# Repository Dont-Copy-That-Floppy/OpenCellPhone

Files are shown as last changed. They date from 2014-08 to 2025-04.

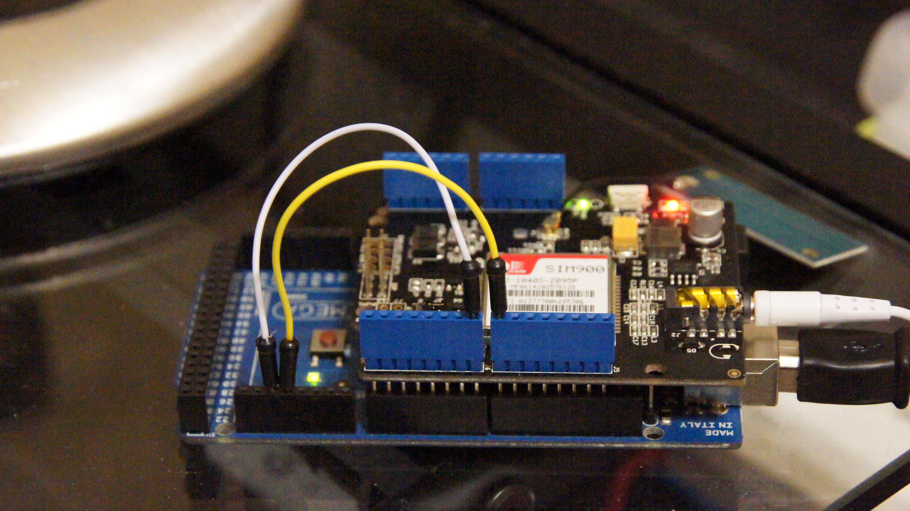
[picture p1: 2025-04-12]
Images/Hardware_Serial.JPG

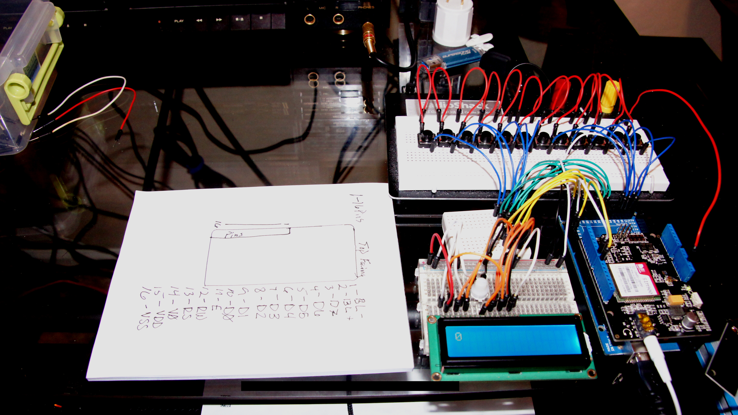
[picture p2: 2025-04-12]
Images/Pre-PrototypePhone_Breadboard.JPG

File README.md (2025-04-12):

# OpenCellPhone

**An open hardware + software cell phone using the global GSM network.**

Arduino-based and fully open-source, OpenCellPhone is a DIY mobile phone project that runs on AT commands, handles SMS/calls, and supports a touch-based interface with a custom-built GUI.

[2014/15 Hackaday Quarterfinalist](https://hackaday.io/project/2478-open-source-cell-phone)

---

## 🚀 Features

- Full support for **SMS send/receive**
- **Touch-based dial pad** and passcode lock screen
- **Call handling** (dial, receive, hang up)
- Basic **notifications**, **call timer**, and **incoming caller display**
- Real-time **clock display** from GSM module (`AT+CCLK`)
- Visual **signal strength** display (`AT+CSQ`)
- **Low-power display handling** with timeout/dim/sleep modes

---

## 🧠 Planned and Future Features

### Needed Features

- Lookup table for pixel width for screen formatting
- Sent SMS display and storage
- Secondary storage for messages
- Emergency calling from passcode screen
- In-call volume adjustment
- Call waiting support (`AT+CHLD`)
- Missed call tracking
- SMS management (delete, reorder, store)
- Signal strength meter
- Re-dial last number (`ATDL`)
- Notification screen with better intelligence

### Future Features

- Bluetooth & FM Radio
- Contact List / Phone Book
- Adjustable screen brightness
- Airplane mode (`AT+CFUN`)
- SMS sorting by sender/contact
- Swipe gestures for UI
- MMS view/send, image handling
- Light sensor and auto-brightness
- MP3/audio playback
- GPS & accelerometer
- Display output
- Web browser
- Ringtones
- Configurable settings via touch UI

---

## 📋 SIM Limitations

- SIM card storage is limited to **30 SMS messages**

---

## ⚙️ Build Info

### Architecture

- Built with **Arduino IDE**
- Written in C/C++ with **low-level serial AT command** integration
- GUI rendered using **RA8875 touchscreen driver**
- Touchscreen and backlight managed through **PWM and pin control**

### Libraries & Tools

- `RA8875` display/touch driver
- Standard `Serial`, `Wire`, and `SPI` Arduino libs
- Custom utility functions for character buffering and cursor logic

---

## 🧪 AT Command References

| Command | Description |
|---|---|
| `ATD*99#` | Dial Access Point |
| `AT+CGDCONT=1,"IP","access.point.name"` | Defines PDP context |
| `AT+VRX` | Record in-call audio |
| `AT+COPS=?` | List available networks |
| `AT+CSQ` | Check signal strength |
| `ATDL` | Redial last number |
| `AT+CHLD` | Call waiting options |

---

## 🧰 Development Setup

### Folder Structure

```text
/PrototypePhone
│
├── /lib                # Optional custom libraries
├── PrototypePhone.ino  # main file

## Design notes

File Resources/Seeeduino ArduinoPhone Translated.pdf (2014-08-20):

### 1. Introduction

ArduinoPhone is a simple wireless telephone device, you can simply realize the phone, answer the phone, send and receive information and Time display function. Communication section uses GPRS Shield to achieve, the display section using TFT Touch Shield, wrote a more complex the firmware, to achieve the UI management, and program screen click function.
The difficulty is:
1. UI management
2. Alphabetic keyboard input
3. Effect zoned screen
4. Serial data processing

### 2. Hardware 2.1 Use Module

- Arduino / Seeeduino
- GPRS Shield
- TFT Touch Shield
- Grove - RTC
- Homemade 7.4V lithium battery charging plate, circuit diagrams attached, you can also use 9V battery

### 2.2 Hardware Connection

GPRS Shield serial communication using hard, TFT Touch Shield 1.0 version (non-SPI interface), a simple repair changed code compatible with version 2.0 TFT Touch Shield Grove -. RTC using I2C interface.
Connection as shown in Figure 2-1.

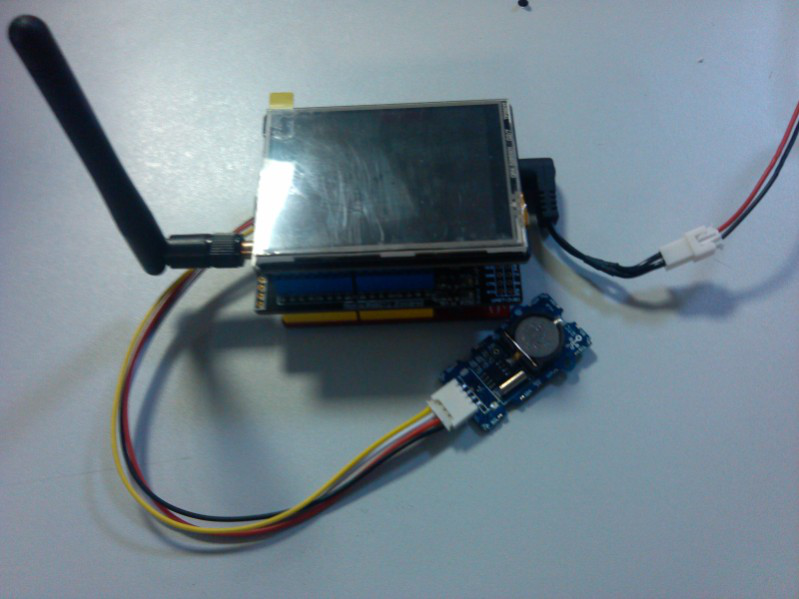
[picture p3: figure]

Figure 2-1 hardware connection diagram

### 3 Software 3.1 Software Process

Main frame is a state machine to switch between the respective states, the following seven states:
- ST_TIME: time mode, real-time displays the current time in this mode, by pressing on the two TFT
- Key to switch to ST_CALL and ST_SMS, if you receive a message, then switched to ST_GETMSG, such as
- If a call comes in, switch to ST_GETCALL.
- ST_CALL: phone mode, then enter the number and dial. Press the call button to switch to ST_CALLING. To Right drag TFT switching to ST_TIME, drag left to switch to ST_SMS
- ST_CALLING: talk mode, if the call ends, the return ST_CALL
- ST_GETCALL: phone into the state, you can use the Accept TFT is turned on or Hand up phone hang
- Off calls. After the call back to the previous state.
- ST_SMS: send a message mode, you can enter the recipient's number and information content, I switched to the Send key
- ST_SENDSMS. Right drag TFT switching to ST_CALL, drag left to switch to ST_GETMSG.
- ST_SENDSMS: Send state, after the information has been sent to return ST_SMS
- ST_GETMSG: read information, press Return TFT can return on a state.

### 3.2 Serial Data Processing

GPRS Shield with Arduino via serial communication, and communication is the process immediately, so opened the Timer 1 every 10ms to detect whether the serial data, if there is data, the stored data to the serial port of a global array serialdata in and the global variable serialGot set. In each of the above said, the state will determine serialGot cycle is valid, If so, the data is read in serialDta and determines the meaning of the data. For example, serial port to receive the "RING" This String, indicating a call comes in, which is switching state, switch to talk mode.

### 3.3 Key letter input

Nokia as we usually like to use, such as pressing a button on the 1st consecutive time, will print a different letter, when build, click when it is a, two under is b, three times is c. To achieve this, you need to determine some time, press After that, if there is the same key within a certain period of time pressed, the buttons as a continuous process. There are many ways to obtain the time interval can be achieved, I tried that millis () function, which returns when the system is running between, the unit is ms. Time intervals tested and found 600ms results were better.

### 3.4 Zoned Screen Effect

You first need to get a lot of data click and slide the screen. Then analyze the data to draw some regularity. When there is a touch behavior when the data through a simple judgment, throw a queue inside, make some judgments, to determine the current behavior is to click on the touch screen or a draw. Here's a little too simple to write, you need to peruse the source code to discover the principle difficulty is debugging parameters.

### 3.5 Instructions for use:

Software process description which has probably explains the use, in fact, this is similar to an ordinary cell phone, does not require much Description and functions are relatively simple.

### 4 Needs To Be Improved

Overall, this firmware to complete a simple function, a lot of areas for improvement:
- Interface design can be more beautiful, because now use TFT Touch Shield 1.0 is no SD card, while Arduino resources within relatively tight, so this part is very difficult to carry out, if you use TFT 2.0, will A lot easier
- Aspects of receiving information, or that problem, with limited resources, so the information can not keep up!
- Address book, you can add this feature, you need to SD cards and other storage devices power down
- Time settings, this due to time constraints, did not do
- Alarm, again, time is running out!
- Other ~

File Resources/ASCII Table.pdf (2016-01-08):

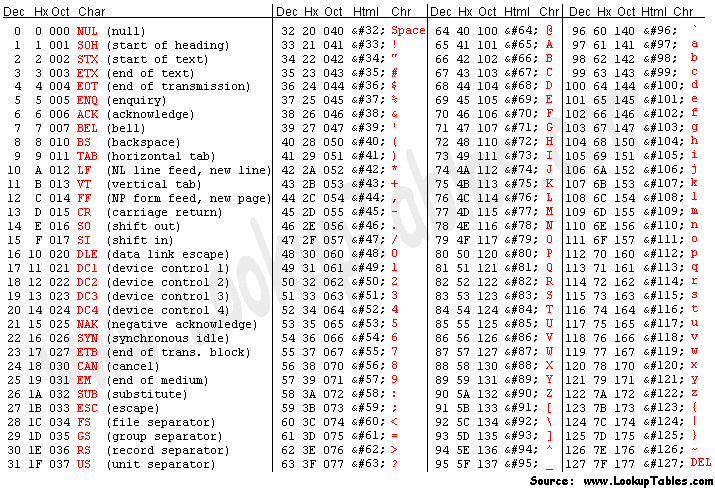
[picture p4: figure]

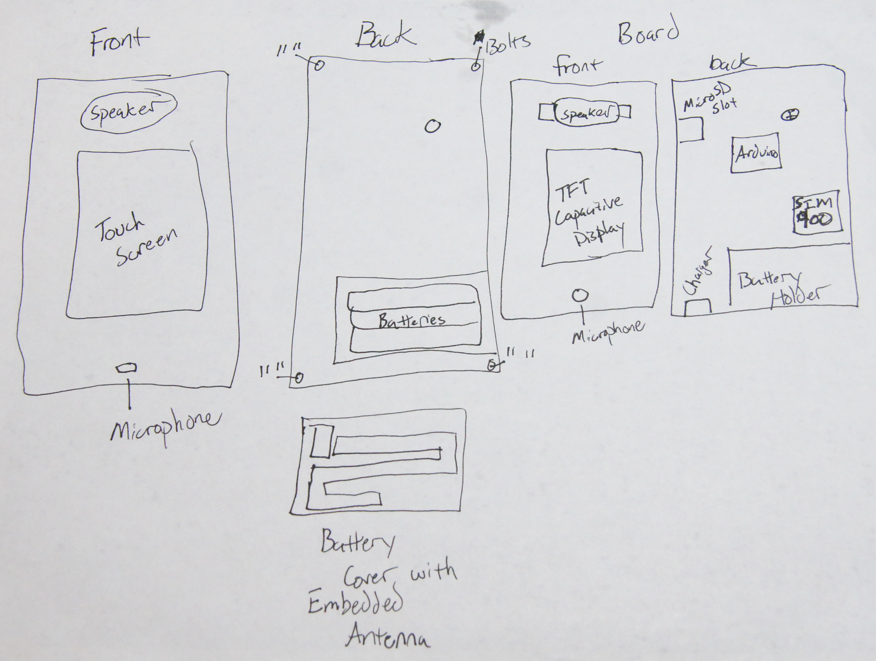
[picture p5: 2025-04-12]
Images/Concept_handdrawing.jpg

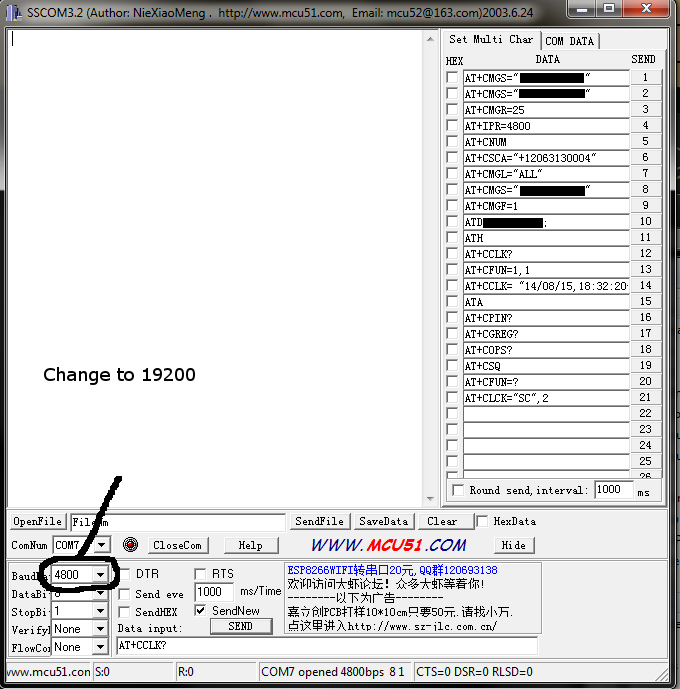
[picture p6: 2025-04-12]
Images/sscom19200.PNG

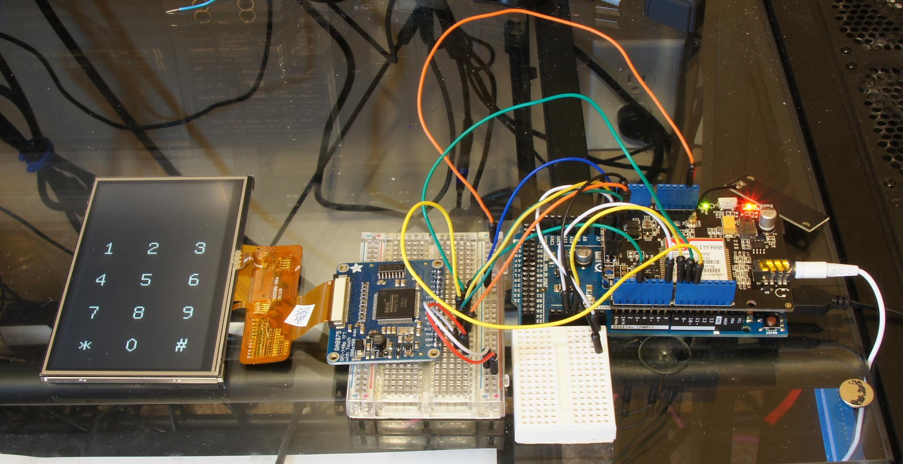
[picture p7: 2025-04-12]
Images/Prototype 8-23.JPG

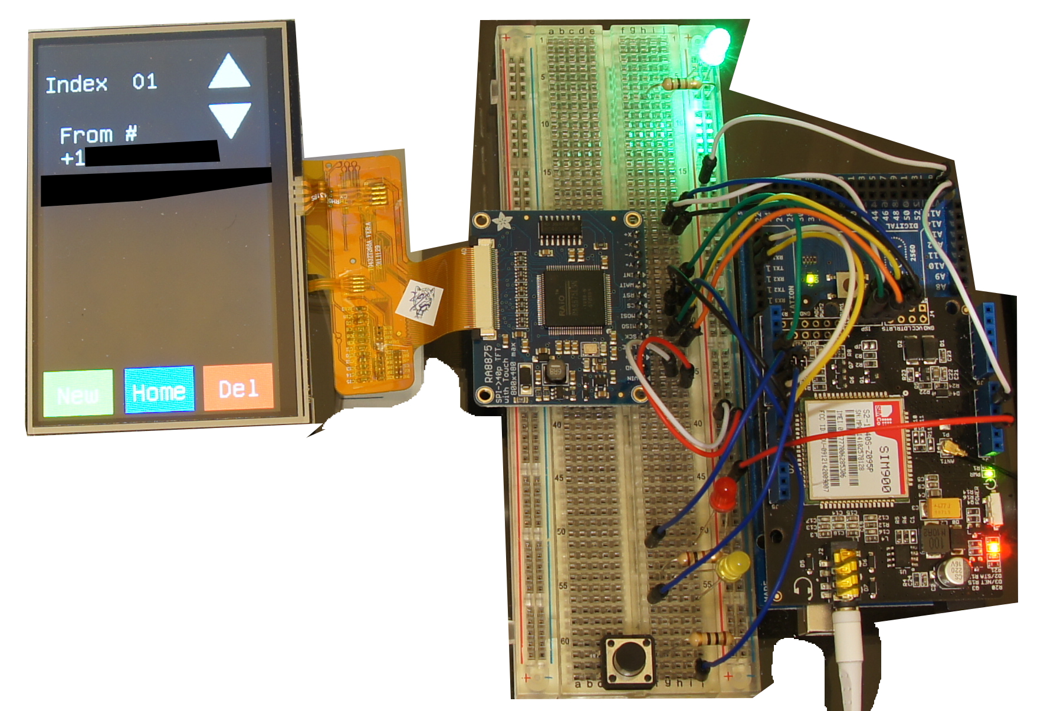
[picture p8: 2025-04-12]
Images/Screen Pictures/SMS_Screen.JPG

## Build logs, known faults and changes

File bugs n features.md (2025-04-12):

---

# 📋 Bugs

- [ ] Delete message needs to go to the **nearest SMS**
- [ ] **Time update** on first start-up takes longer than usual
- [ ] **Not all touches** are registered
- [ ] `clearNotifications` call on line 433 needs more intelligence
- [ ] Prevent user/system from navigating **past available SMS messages**
- [ ] **Reorganize** SMS messages when a lower-numbered one is deleted

---

# 🚧 Needed Features

- [ ] Lookup table for **pixel width** (for screen formatting and text)
- [ ] Function for **user input** to change text position
- [ ] **SMS send** function
- [ ] Ability to **read sent messages**
- [ ] **Store SMS** on secondary storage
- [ ] **Emergency call** from passcode screen
- [ ] Store **missed calls count and number**
- [ ] **Notification screen**
- [ ] **Call time** counter
- [ ] **Call record** screen and data
- [ ] **Clear notifications** functionality
- [ ] **In-call volume** control
- [ ] **Signal strength** display (`AT+CSQ`)
- [ ] **Redial** previous number (`ATDL`)
- [ ] **Call waiting** support (`AT+CHLD=<N>`)
  - `N = 1`: terminate current call, answer call waiting  
  - `N = 2`: set current call to busy, answer waiting call

---

# 🌟 Future Features

- [ ] **Bluetooth**
- [ ] **FM Radio**
- [ ] **Contact list / Phone book**
- [ ] Adjustable **display brightness**
- [ ] **Airplane Mode**
  - Enable: `AT+CFUN=4`
  - Disable: `AT+CFUN=1`
- [ ] Sort SMS by **sender** or **contact**
- [ ] **Swipe screen** left-right for sidebar (e.g., volume control)
- [ ] Show **character limit** during SMS composition
- [ ] **View MMS**
- [ ] **Send MMS**
- [ ] **View images** in MMS
- [ ] **Swipe to clear** notifications
- [ ] **Light sensor** for proximity-based brightness control
- [ ] **Transistor-controlled** ground for speaker (only active in-call)
- [ ] **Transistor-controlled** power for display driver (remove `digitalRead`)
- [ ] Dedicated **Settings screen**
  - Change **screen timeout**
  - Add/Remove **passcode**
  - Adjust **display brightness**
  - Configure **auto brightness thresholds**
  - Set SMS **viewing index manually**
- [ ] **Accelerometer** support (e.g., auto orientation)
- [ ] Use **custom ringtones**
- [ ] **MP3/Audio player**
- [ ] **GPS** sensor
- [ ] **Display-Out** support
- [ ] **Web browser**

---

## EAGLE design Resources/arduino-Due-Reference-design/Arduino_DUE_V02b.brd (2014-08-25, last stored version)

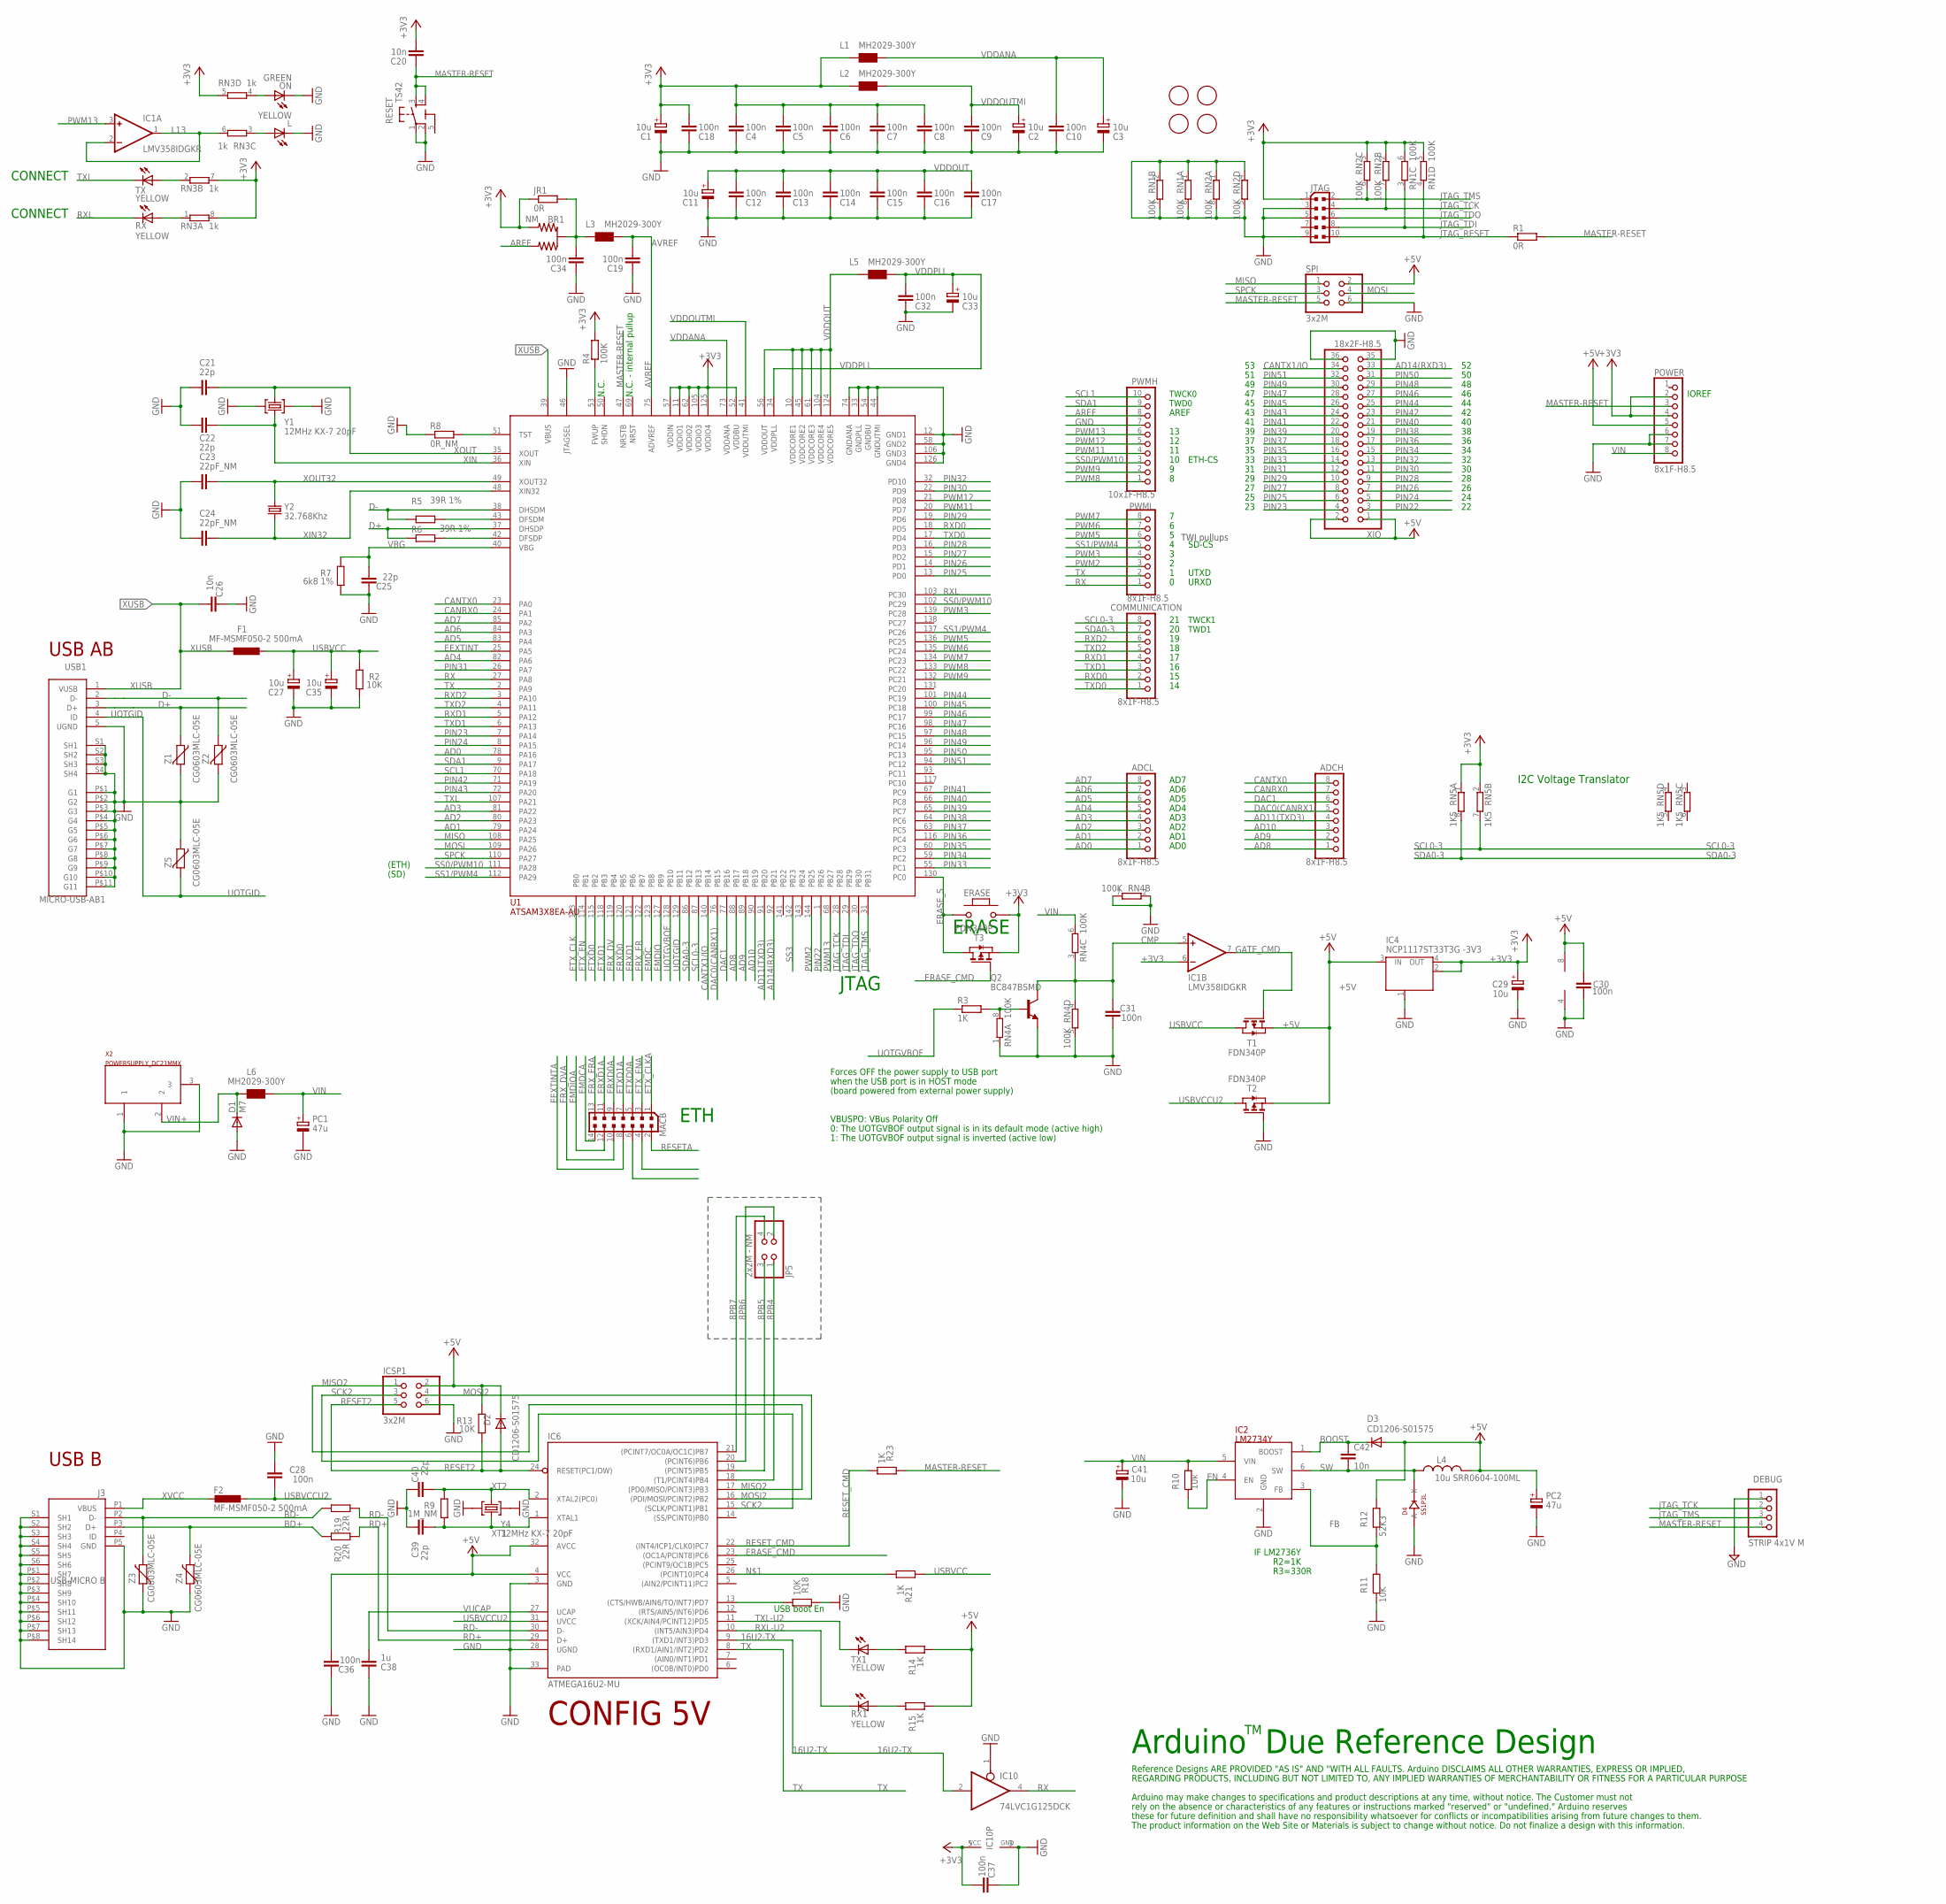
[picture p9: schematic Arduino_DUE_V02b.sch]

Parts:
ADCH: 8x1F-H8.5; 1X08
ADCL: 8x1F-H8.5; 1X08
BR1: NM; J0402
C1, C2, C3, C11, C27, C29, C33, C35, C41: 10u; SMC_B
C4, C5, C6, C7, C8, C9, C10, C12, C13, C14, C15, C16, C17, C18, C19, C28, C30, C31, C32, C34, C36, C37: 100n; C0402
C20, C26: 10n; C0402
C21, C22, C25, C39, C40: 22p; C0402
C23, C24: 22pF_NM; C0402
C38: 1u; C0402
C42: 10n; C0603-ROUND
COMMUNICATION: 8x1F-H8.5; 1X08
D1: M7; SMB
D2, D3: CD1206-S01575; MINIMELF
D4: SS1P3L; DO220AAL
DEBUG: STRIP 4x1V M; 1X04
ERASE: MYSMD_PB157; SMD_157SW
F1, F2: MF-MSMF050-2 500mA; L1812
FID1, FID2, FID3, FID4: FIDUCIALMOUNT; FIDUCIA-MOUNT
IC1: LMV358IDGKR; MSOP08
IC2: LM2734Y; SOT23-6
IC4: NCP1117ST33T3G -3V3; SOT223
IC6: ATMEGA16U2-MU; MLF32
IC10: 74LVC1G125DCK; SC70-5
ICSP1: 3x2M; 2X03
J3: USB-MICRO B; CON2_USB_MICRO_B_AT
JP5: 2x2M - NM; 2X02
JR1: 0R; R0402
JTAG: PINHEAD_PINHD-2X5PASSO127; PINHEAD_2X05_127
L: YELLOW; CHIP-LED0805
L1, L2, L3, L5, L6: MH2029-300Y; 0805
L4: 10u SRR0604-100ML; SRR0604
MACB: PINHEAD_PINHD-2X7PASSO127; PINHEAD_2X07_127
ON: GREEN; CHIP-LED0805
PC1, PC2: 47u; PANASONIC_D
POWER: 8x1F-H8.5; 1X08
PWMH: 10x1F-H8.5; 1X10
PWML: 8x1F-H8.5; 1X08
Q2: BC847BSMD; SOT23
R1: 0R; R0402
R2, R13, R18: 10K; R0402
R3, R14, R15, R21, R23: 1K; R0402
R4: 100K; R0402
R5, R6: 39R 1%; R0402
R7: 6k8 1%; R0603-ROUND
R8: 0R_NM; R0402
R9: 1M_NM; R0402
R10: 10k; R0402
R11: 10K; R0603-ROUND
R12: 52K3; R0603-ROUND
R19, R20: 22R; R0402
RESET: TS42
RN1, RN2, RN4: 100K; CAT16
RN3: 1k; CAY16
RN5: 1K5; CAT16
RX, RX1: YELLOW; CHIP-LED0805
SPI: 3x2M; 2X03
T1, T2, T3: FDN340P; SOT-23
TX, TX1: YELLOW; CHIP-LED0805
U1: ATSAM3X8EA-AU; LQFP144
USB1: MICRO-USB-AB1; MCR-AB1-S-RA-SMT
X2: POWERSUPPLY_DC21MMX; POWERSUPPLY_DC-21MM
XIO: 18x2F-H8.5; 2X18
Y1, Y4: 12MHz KX-7 20pF; CRYSTAL-3.2-2.5
Y2: 32.768Khz; RESONATOR_EPSON_FC_145
Z1, Z2, Z3, Z4, Z5: CG0603MLC-05E; CT/CN0603

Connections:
5-GND: RESET.5 (5-GND)
8PB4: IC6.18 ((T1/PCINT4)PB4), JP5.1
8PB5: IC6.19 ((PCINT5)PB5), JP5.3
8PB6: IC6.20 ((PCINT6)PB6), JP5.2
8PB7: IC6.21 ((PCINT7/OC0A/OC1C)PB7), JP5.4
16U2-TX: IC6.9 ((TXD1/INT3)PD3), IC10.2 (I)
+3V3: BR1.3 (2), C1.+, C4.2, C5.2, C6.2, C7.2, C8.2, C18.2, C20.2, C29.+, C37.1, ERASE.1, IC1.6 (-IN), IC4.2 (OUT), IC4.4 (OUT), IC10.5 (VCC), JR1.1, JTAG.1, L1.1, L2.1, POWER.2, POWER.4, R4.2, RN1.5 (2), RN1.6 (2), RN2.2 (1), RN2.3 (1), RN3.5 (2), RN3.7 (2), RN3.8 (2), RN5.1, RN5.2 (1), T3.2 (S), U1.11 (VDDIO1), U1.52 (VDDBU), U1.57 (VDDIN), U1.62 (VDDIO2), U1.105 (VDDIO3), U1.125 (VDDIO4)
+5V: C30.2, C36.1, D2.C, D3.A, IC1.8 (V+), IC4.3 (IN), IC6.4 (VCC), IC6.32 (AVCC), ICSP1.2, L4.P$2 (2), PC2.+, POWER.5, R12.1, R13.2, R14.1, R15.1, SPI.2, T1.2 (S), T2.2 (S), XIO.1, XIO.2
AD0: ADCL.1, U1.78 (PA16)
AD1: ADCL.2, U1.79 (PA24)
AD2: ADCL.3, U1.80 (PA23)
AD3: ADCL.4, U1.81 (PA22)
AD4: ADCL.5, U1.82 (PA6)
AD5: ADCL.6, U1.83 (PA4)
AD6: ADCL.7, U1.84 (PA3)
AD7: ADCL.8, U1.85 (PA2)
AD8: ADCH.1, U1.88 (PB17)
AD9: ADCH.2, U1.89 (PB18)
AD10: ADCH.3, U1.90 (PB19)
AD11(TXD3): ADCH.4, U1.91 (PB20)
AD14(RXD3): U1.92 (PB21), XIO.33
AREF: BR1.1, PWMH.8
AVREF: C19.2, L3.2, U1.75 (ADVREF)
AVREFL: BR1.2 (C), C34.2, JR1.2, L3.1
BD+: J3.P3 (D+), R20.2, Z4.2
BD-: J3.P2 (D-), R19.2, Z3.2
BOOST: C42.1, D3.C, IC2.1 (BOOST)
CANRX0: ADCH.7, U1.24 (PA1)
CANTX0: ADCH.8, U1.23 (PA0)
CANTX1/IO: U1.140 (PB14), XIO.34
CMP: C31.2, IC1.5 (+IN), Q2.3 (C), RN4.3 (1), RN4.4 (1)
D+: R6.1, U1.37 (DHSDP), USB1.3 (D+), Z1.1
D-: R5.1, U1.38 (DHSDM), USB1.2 (D-), Z2.1
DAC0(CANRX1): ADCH.5, U1.76 (PB15)
DAC1: ADCH.6, U1.77 (PB16)
DTR: IC6.13 ((CTS/HWB/AIN6/TO/INT7)PD7), R18.1
EEXTINT: U1.25 (PA5)
EEXTINTA: MACB.8
EMDC: U1.123 (PB8)
EMDCA: MACB.14
EMDIO: U1.127 (PB9)
EMDIOA: MACB.12 (13)
EN: IC2.4 (EN), R10.2
ERASE_CMD: IC6.23 ((OC1A/PCINT8)PC6), T3.3 (G)
ERASE_S: ERASE.2, T3.1 (D), U1.130 (PC0)
ERXD0: U1.120 (PB5)
ERXD0A: MACB.9
ERXD1: U1.121 (PB6)
ERXD1A: MACB.11
ERX_DV: U1.119 (PB4)
ERX_DVA: MACB.10
ERX_ER: U1.122 (PB7)
ERX_ERA: MACB.13 (12)
ETXD0: U1.115 (PB2)
ETXD0A: MACB.5
ETXD1: U1.118 (PB3)
ETXD1A: MACB.7
ETX_CLK: U1.113 (PB0)
ETX_CLKA: MACB.1
ETX_EN: U1.114 (PB1)
ETX_ENA: MACB.3
FB: IC2.3 (FB), R11.1, R12.2
GATE_CMD: IC1.7 (OUT), T1.3 (G)
GND: C1.-, C2.-, C3.-, C4.1, C5.1, C6.1, C7.1, C8.1, C9.1, C10.1, C11.-, C12.1, C13.1, C14.1, C15.1, C16.1, C17.1, C18.1, C19.1, C21.2, C22.2, C23.2, C24.2, C25.2, C26.2, C27.-, C28.2, C29.-, C30.1, C31.1, C32.1, C33.-, C34.1, C35.-, C36.2, C37.2, C38.2, C39.2, C40.2, C41.-, D1.A, D4.P$2 (A), DEBUG.1, IC1.4 (V-), IC2.2 (GND), IC4.1 (GND/ADJ), IC6.3 (GND), IC6.28 (UGND), IC6.33 (PAD), IC10.1 (OE), IC10.3 (GND), ICSP1.6, J3.P5 (GND), J3.P$1 (SH7), J3.P$2 (SH8), J3.P$3 (SH9), J3.P$4 (SH10), J3.P$5 (SH11), J3.P$6 (SH12), J3.P$7 (SH13), J3.P$8 (SH14), J3.S1 (SH1), J3.S2 (SH2), J3.S3 (SH3), J3.S4 (SH4), J3.S5 (SH5), J3.S6 (SH6), JTAG.3, JTAG.5, JTAG.9, L.C, ON.C, PC1.-, PC2.-, POWER.6, POWER.7, PWMH.7, Q2.2 (E), R2.1, R7.1, R8.1, R11.2, R18.2, RESET.1, RESET.2, RN1.1, RN1.2 (1), RN1.7 (2), RN1.8 (2), RN2.1, RN2.4 (1), RN2.5 (2), RN2.8 (2), RN4.1, RN4.2 (1), RN4.5 (2), RN4.7 (2), SPI.6, T2.3 (G), U1.12 (GND1), U1.33 (GNDPLL), U1.44 (GNDUTMI), U1.46 (JTAGSEL), U1.54 (GNDBU), U1.58 (GND2), U1.74 (GNDANA), U1.106 (GND3), U1.126 (GND4), USB1.5 (UGND), USB1.P$1 (G1), USB1.P$2 (G2), USB1.P$3 (G3), USB1.P$4 (G4), USB1.P$5 (G5), USB1.P$6 (G6), USB1.P$7 (G7), USB1.P$8 (G8), USB1.P$9 (G9), USB1.P$10 (G10), USB1.P$11 (G11), USB1.S1 (SH1), USB1.S2 (SH2)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
JTAG_RESET: JTAG.10, R1.1, RN1.4 (1)
JTAG_TCK: DEBUG.2, JTAG.4, RN2.7 (2), U1.28 (PB28)
JTAG_TDI: JTAG.8, RN1.3 (1), U1.29 (PB29)
JTAG_TDO: JTAG.6, U1.30 (PB30)
JTAG_TMS: DEBUG.3, JTAG.2, RN2.6 (2), U1.31 (PB31)
L13: IC1.1 (OUT), IC1.2 (-IN), RN3.6 (2)
MASTER-RESET: C20.1, DEBUG.4, POWER.3, R1.2, R23.2, RESET.3, RESET.4, SPI.5, U1.47 (NRSTB)
MISO: SPI.1, U1.108 (PA25)
MISO2: IC6.17 ((PD0/MISO/PCINT3)PB3), ICSP1.1
MOSI: SPI.4, U1.109 (PA26)
MOSI2: IC6.16 ((PDI/MOSI/PCINT2)PB2), ICSP1.4
unnamed: IC6.26 ((PCINT10)PC4), R21.1
unnamed: L.A, RN3.3 (1)
unnamed: ON.A, RN3.4 (1)
unnamed: R15.2, RX1.A
unnamed: R8.2, U1.51 (TST)
unnamed: Q2.1 (B), R3.2, RN4.8 (2)
unnamed: R4.1, U1.53 (FWUP)
unnamed: R5.2, U1.43 (DFSDM)
unnamed: R6.2, U1.42 (DFSDP)
unnamed: R14.2, TX1.A
unnamed: RN3.1, RX.A
unnamed: RN3.2 (1), TX.A
PIN22: U1.1 (PB26), XIO.3
PIN23: U1.7 (PA14), XIO.4
PIN24: U1.8 (PA15), XIO.5
PIN25: U1.13 (PD0), XIO.6
PIN26: U1.14 (PD1), XIO.7
PIN27: U1.15 (PD2), XIO.8
PIN28: U1.16 (PD3), XIO.9
PIN29: U1.19 (PD6), XIO.10
PIN30: U1.22 (PD9), XIO.11
PIN31: U1.26 (PA7), XIO.12
PIN32: U1.32 (PD10), XIO.13
PIN33: U1.55 (PC1), XIO.14
PIN34: U1.59 (PC2), XIO.15
PIN35: U1.60 (PC3), XIO.16
PIN36: U1.116 (PC4), XIO.17
PIN37: U1.63 (PC5), XIO.18
PIN38: U1.64 (PC6), XIO.19
PIN39: U1.65 (PC7), XIO.20
PIN40: U1.66 (PC8), XIO.21
PIN41: U1.67 (PC9), XIO.22
PIN42: U1.71 (PA19), XIO.23
PIN43: U1.72 (PA20), XIO.24
PIN44: U1.101 (PC19), XIO.25
PIN45: U1.100 (PC18), XIO.26
PIN46: U1.99 (PC17), XIO.27
PIN47: U1.98 (PC16), XIO.28
PIN48: U1.97 (PC15), XIO.29
PIN49: U1.96 (PC14), XIO.30
PIN50: U1.95 (PC13), XIO.31
PIN51: U1.94 (PC12), XIO.32
PWM2: PWML.3, U1.144 (PB25)
PWM3: PWML.4, U1.139 (PC28)
PWM5: PWML.6, U1.136 (PC25)
PWM6: PWML.7, U1.135 (PC24)
PWM7: PWML.8, U1.134 (PC23)
PWM8: PWMH.1, U1.133 (PC22)
PWM9: PWMH.2, U1.132 (PC21)
PWM11: PWMH.4, U1.20 (PD7)
PWM12: PWMH.5, U1.21 (PD8)
PWM13: IC1.3 (+IN), PWMH.6, U1.68 (PB27)
RD+: IC6.29 (D+), R20.1
RD-: IC6.30 (D-), R19.1
RESET2: D2.A, IC6.24 (RESET(PC1/DW)), ICSP1.5, R13.1
RESETA: MACB.2
RESET_CMD: IC6.22 ((INT4/ICP1/CLK0)PC7), R23.1
RX: IC10.4 (O), PWML.1, U1.27 (PA8)
RXD0: COMMUNICATION.2, U1.18 (PD5)
RXD1: COMMUNICATION.4, U1.5 (PA12)
RXD2: COMMUNICATION.6, U1.3 (PA10)
RXL: RX.C, U1.103 (PC30)
RXL-U2: IC6.10 ((INT5/AIN3)PD4), RX1.C
SCK2: IC6.15 ((SCLK/PCINT1)PB1), ICSP1.3
SCL0-3: COMMUNICATION.8, RN5.7 (2), U1.87 (PB13)
SCL1: PWMH.10, U1.70 (PA18)
SDA0-3: COMMUNICATION.7, RN5.8 (2), U1.86 (PB12)
SDA1: PWMH.9, U1.9 (PA17)
SPCK: SPI.3, U1.110 (PA27)
SS0/PWM10: PWMH.3, U1.102 (PC29), U1.111 (PA28)
SS1/PWM4: PWML.5, U1.112 (PA29), U1.137 (PC26)
SS3: U1.142 (PB23)
SW: C42.2, D4.P$1 (K), IC2.6 (SW), L4.P$1 (1)
TX: IC6.8 ((RXD1/AIN1/INT2)PD2), PWML.2, U1.2 (PA9)
TXD0: COMMUNICATION.1, U1.17 (PD4)
TXD1: COMMUNICATION.3, U1.6 (PA13)
TXD2: COMMUNICATION.5, U1.4 (PA11)
TXL: TX.C, U1.107 (PA21)
TXL-U2: IC6.11 ((XCK/AIN4/PCINT12)PD5), TX1.C
UOTGID: U1.129 (PB11), USB1.4 (ID), Z5.2
UOTGVBOF: R3.1, U1.128 (PB10)
USBVCC: C27.+, C35.+, F1.1, R2.2, R21.2, T1.1 (D)
USBVCCU2: C28.1, F2.1, IC6.31 (UVCC), T2.1 (D)
VBG: C25.1, R7.2, U1.40 (VBG)
VDDANA: C3.+, C10.2, L1.2, U1.73 (VDDANA)
VDDOUT: C11.+, C12.2, C13.2, C14.2, C15.2, C16.2, C17.2, L5.1, U1.10 (VDDCORE1), U1.45 (VDDCORE2), U1.56 (VDDOUT), U1.61 (VDDCORE3), U1.104 (VDDCORE4), U1.124 (VDDCORE5)
VDDOUTMI: C2.+, C9.2, L2.2, U1.41 (VDDUTMI)
VDDPLL: C32.2, C33.+, L5.2, U1.34 (VDDPLL)
VIN: C41.+, IC2.5 (VIN), L6.1, PC1.+, POWER.8, R10.1, RN4.6 (2)
VIN+: D1.C, L6.2, X2.2
VUCAP: C38.1, IC6.27 (UCAP)
XIN: C22.1, U1.36 (XIN), Y1.1 (C1)
XIN32: C24.1, U1.48 (XIN32), Y2.P$2 (2)
XOUT: C21.1, U1.35 (XOUT), Y1.3 (C2)
XOUT32: C23.1, U1.49 (XOUT32), Y2.P$1 (1)
XT1: C39.1, IC6.1 (XTAL1), R9.1, Y4.1 (C1)
XT2: C40.1, IC6.2 (XTAL2(PC0)), R9.2, Y4.3 (C2)
XUSB: C26.1, F1.2, U1.39 (VBUS), USB1.1 (VUSB)
XVCC: F2.2, J3.P1 (VBUS)

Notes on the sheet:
TWI pullups
TWCK1
TWD1
IOREF
TWCK0
TWD0
AD1
AD2
AD3
AD4
AD5
AD6
AD0
USB AB
AREF
AD7
SD-CS
Forces OFF the power supply to USB port
when the USB port is in HOST mode
(board powered from external power supply)
N.C.
JTAG
ERASE
CONNECT
VBUSPO: VBus Polarity Off
0: The UOTGVBOF output signal is in its default mode (active high)
1: The UOTGVBOF output signal is inverted (active low)
ETH
UTXD
URXD
(ETH)
(SD)
ETH-CS
I2C Voltage Translator
USB boot En
IF LM2736Y
R2=1K
R3=330R
CONFIG 5V
USB B

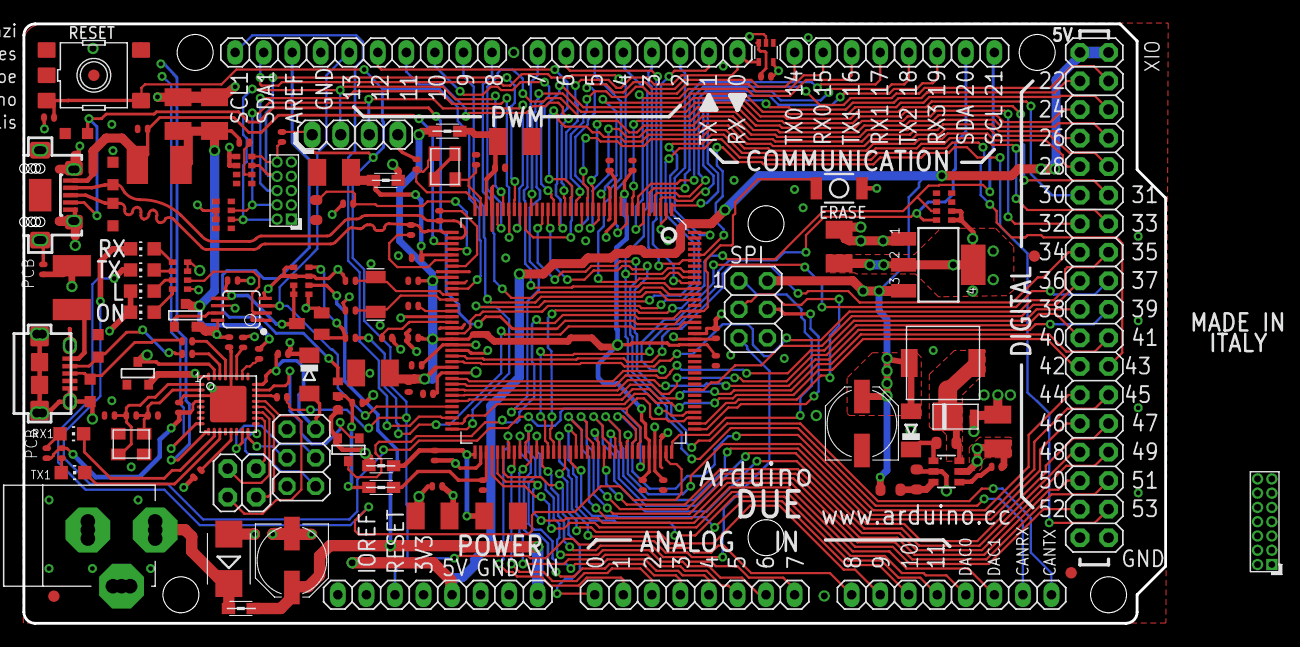
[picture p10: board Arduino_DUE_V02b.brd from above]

Board: 4 copper layers, 101.6 x 53.3 mm, 130 parts (0 on the bottom side), 149 nets.

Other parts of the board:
E$1: DISC

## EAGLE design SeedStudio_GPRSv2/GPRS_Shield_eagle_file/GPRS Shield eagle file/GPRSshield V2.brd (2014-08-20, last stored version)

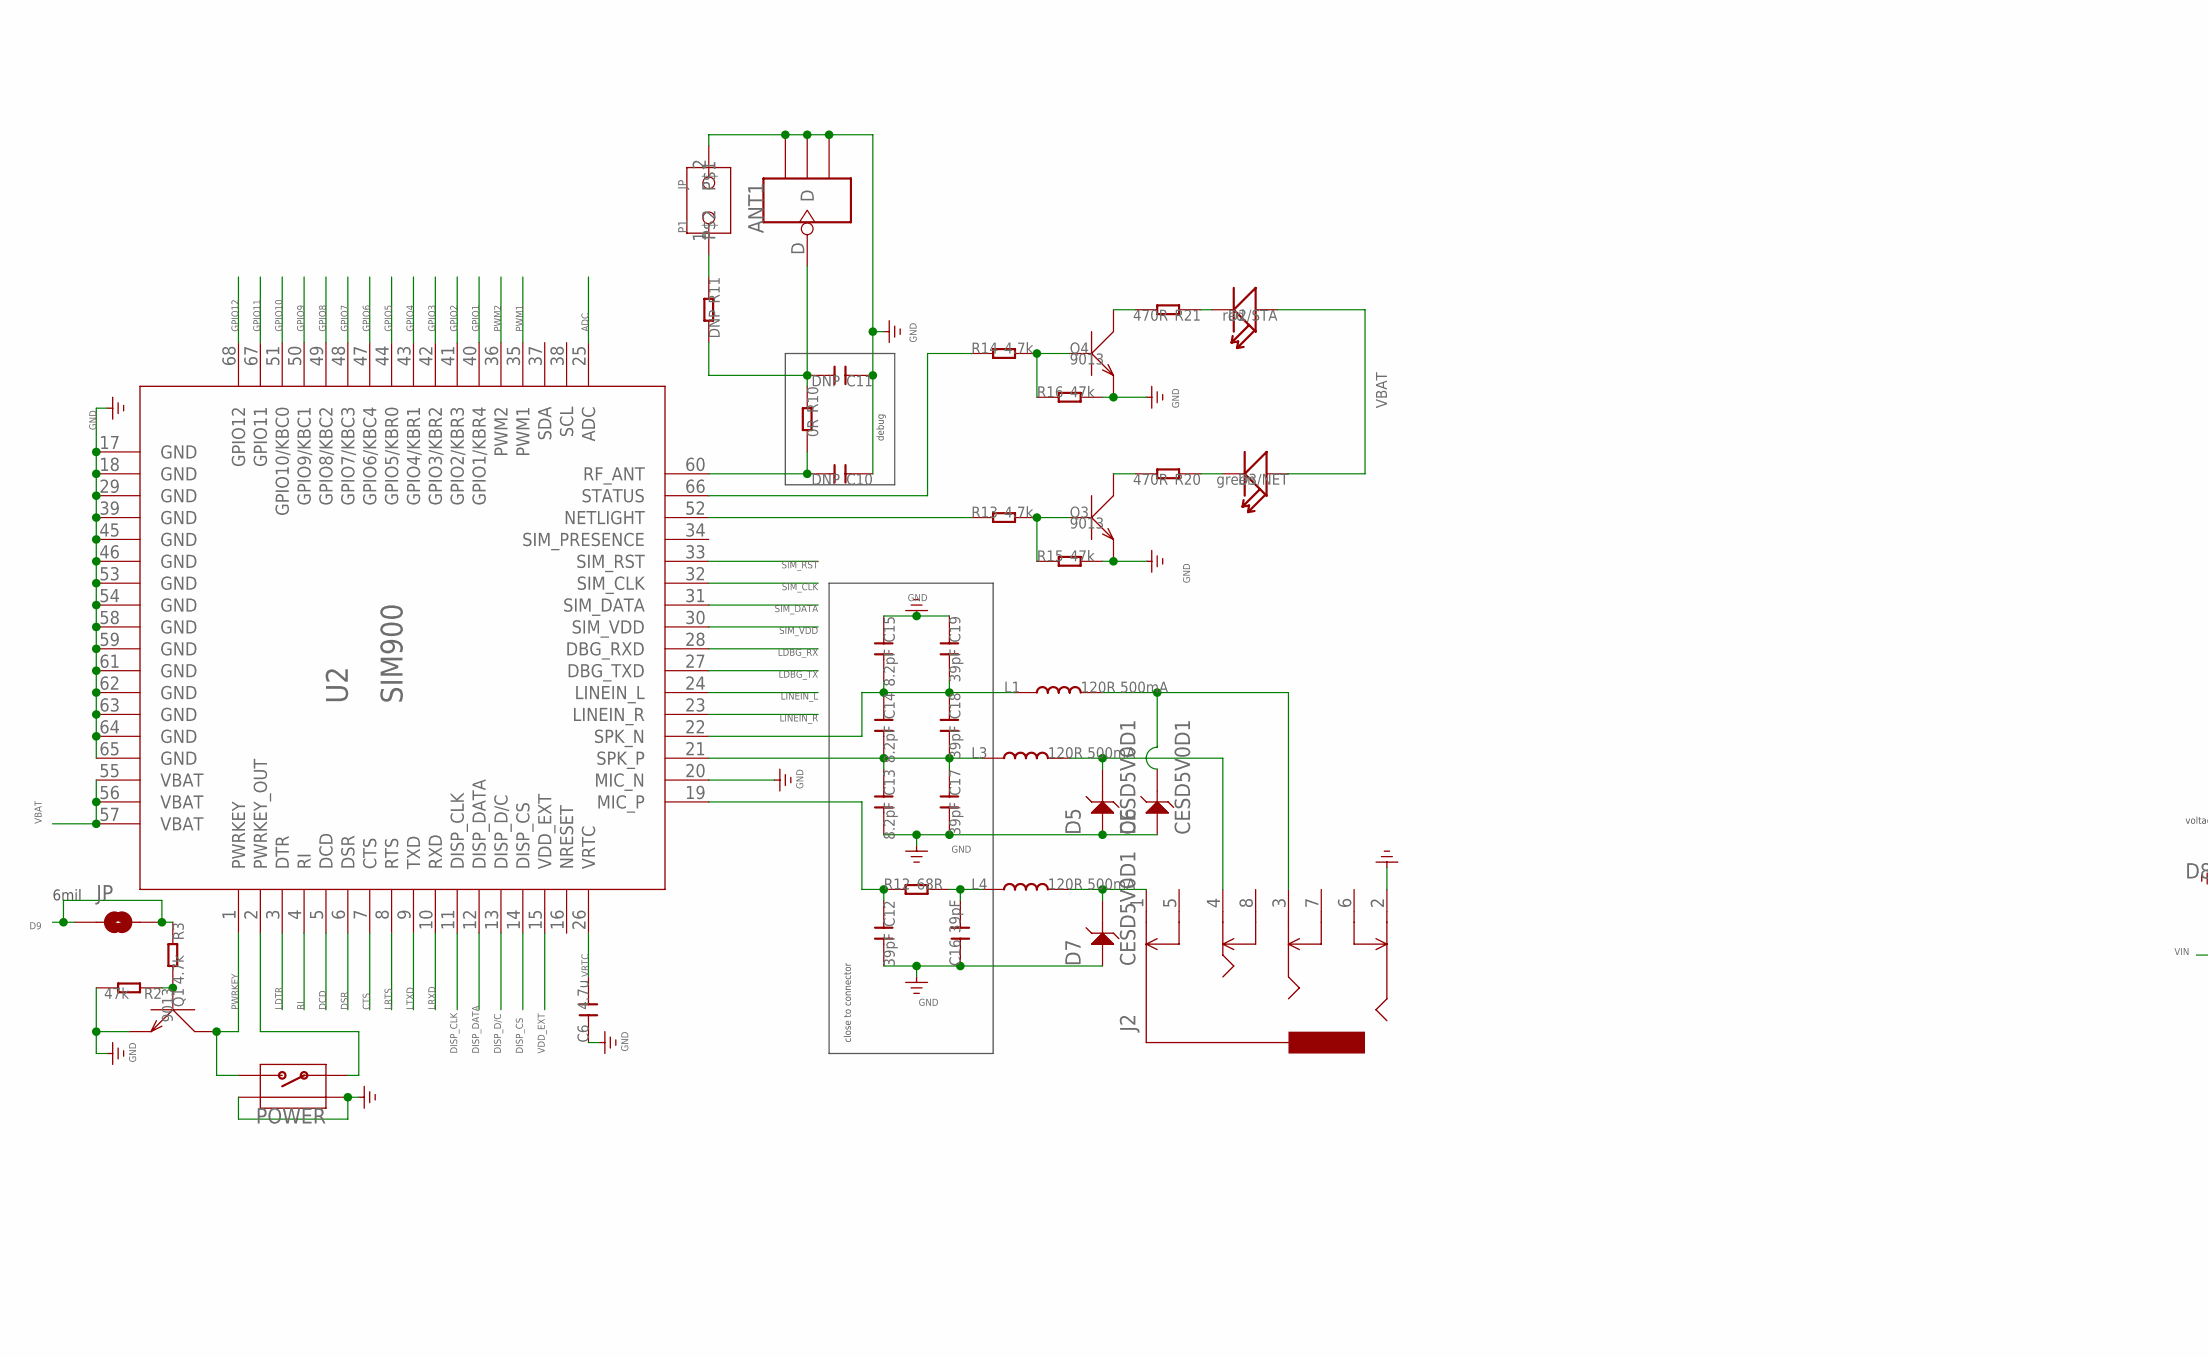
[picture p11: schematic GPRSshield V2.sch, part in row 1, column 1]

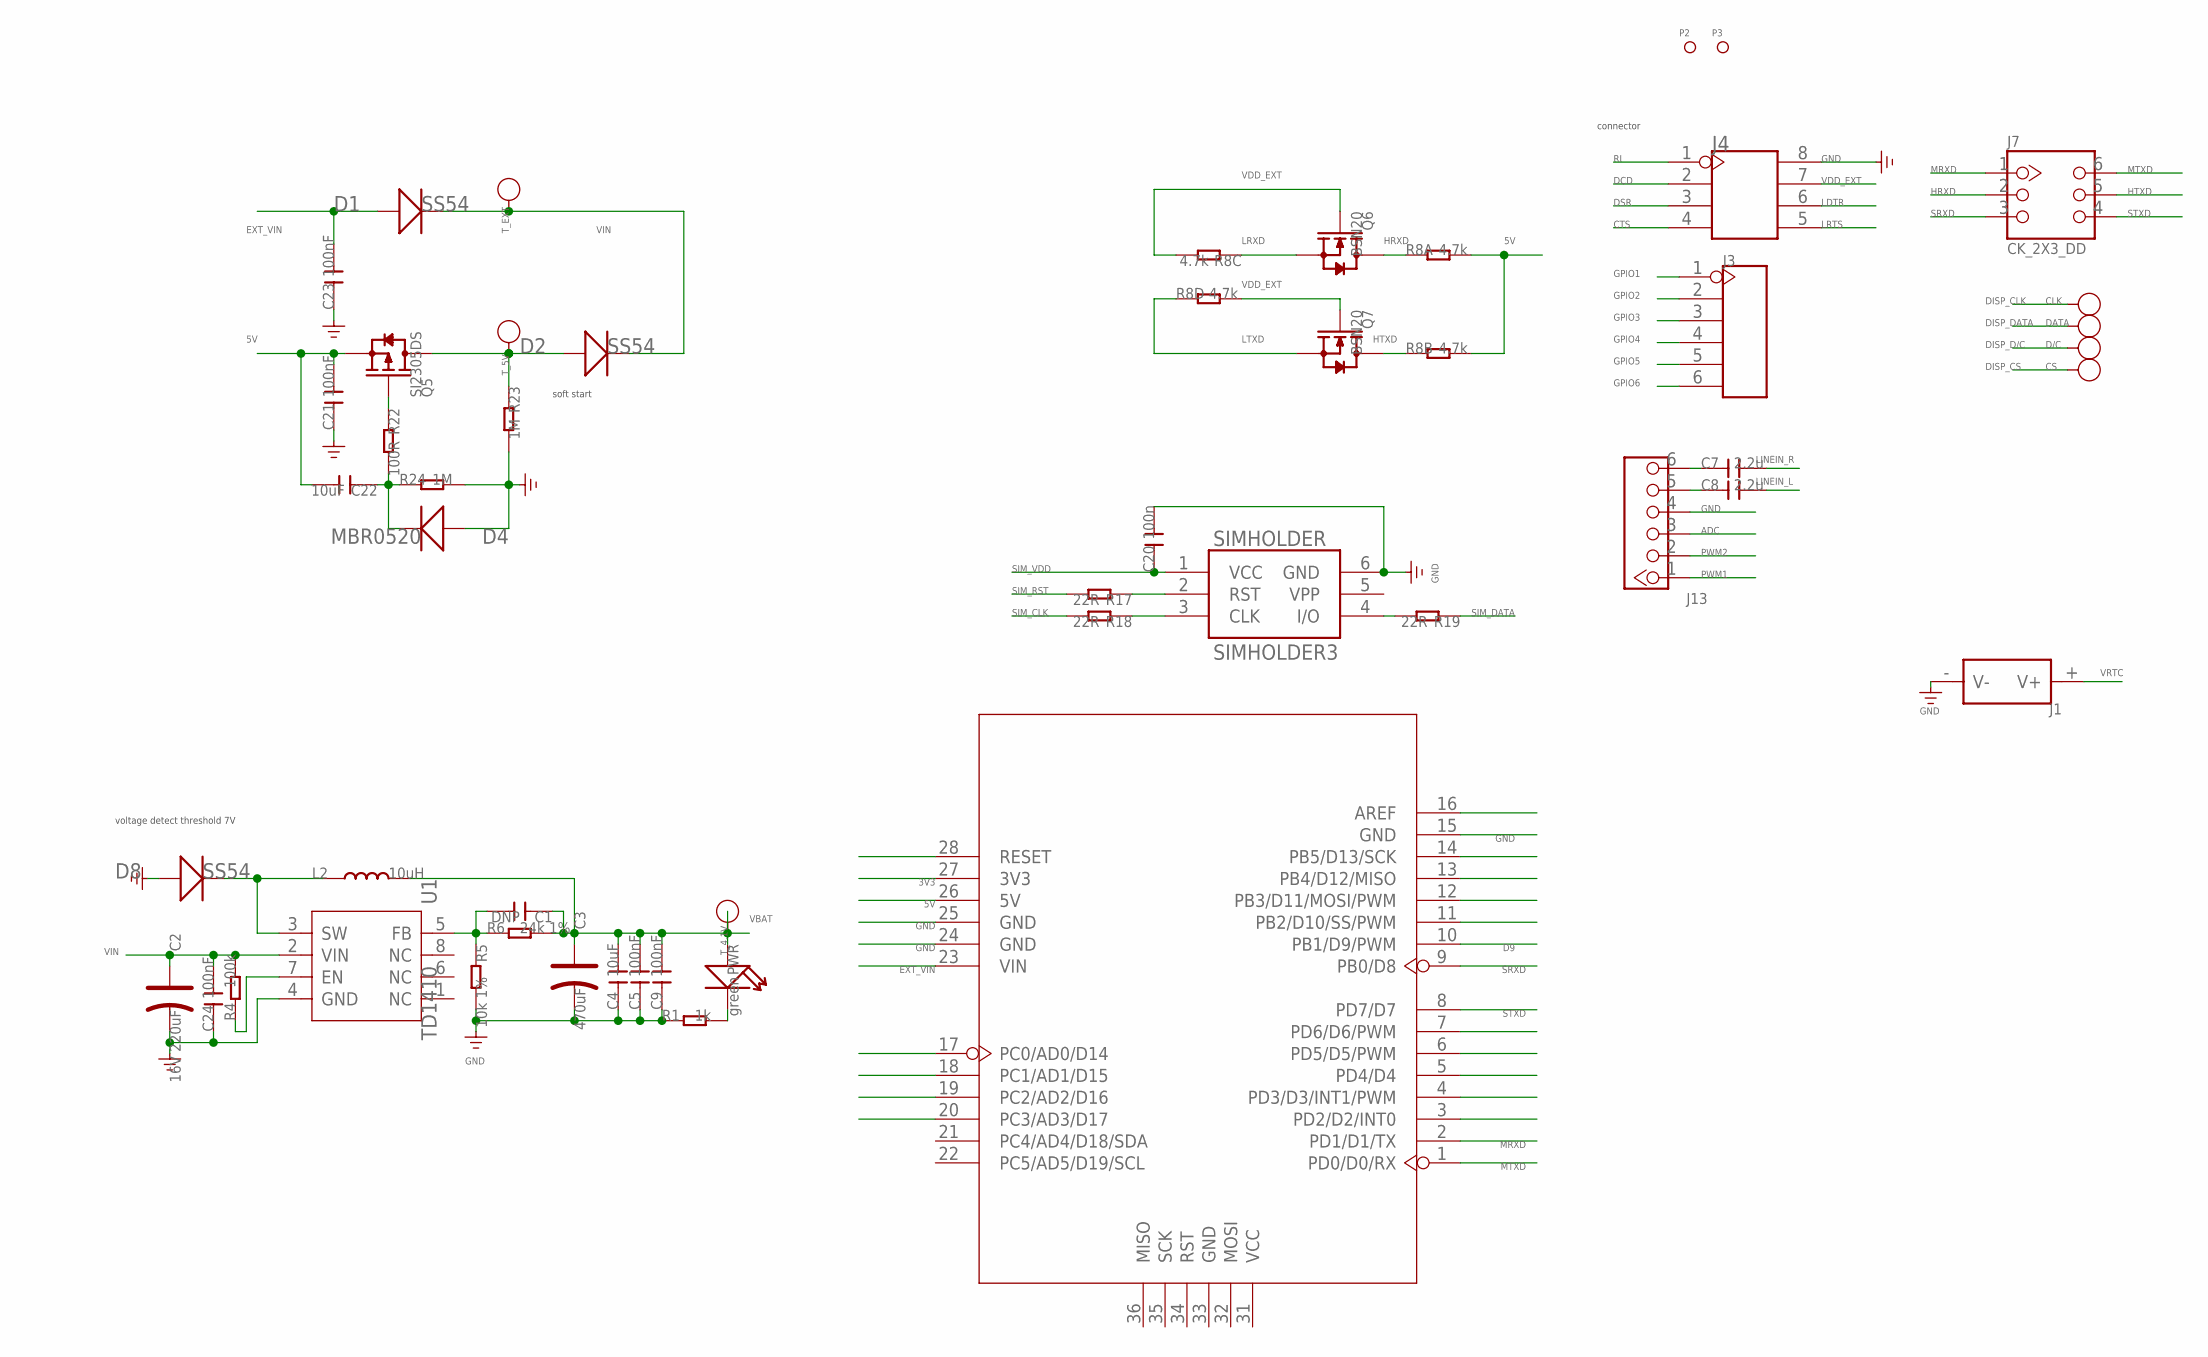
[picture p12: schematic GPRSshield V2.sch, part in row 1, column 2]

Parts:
ANT1: ANTENNA-U-FL; 4P-U-FL
C1, C10, C11: DNP; C0603
C2: 16V 220uF; ELECTRO-SMD-D-5.6MM
C3: 470uF; AVX-D
C4, C22: 10uF; C0805
C5, C9, C21, C23, C24: 100nF; C0603
C6: 4.7u; C0805
C7, C8: 2.2u; C0805
C12, C16, C17, C18, C19: 39pF; C0603
C13, C14, C15: 8.2pF; C0603
C20: 100n; C0603
CLK: PAD-TEST-POINT-CIRCLE'4545'; TP_4545
CS: PAD-TEST-POINT-CIRCLE'4545'; TP_4545
D1, D2, D8: SS54; SMB
D2/STA: red; LED-0603
D3/NET: green; LED-0603
D4: MBR0520; SOD123-2.7X1.6
D5, D6, D7: CESD5V0D1; SOD123-2.7X1.6
D/C: PAD-TEST-POINT-CIRCLE'4545'; TP_4545
DATA: PAD-TEST-POINT-CIRCLE'4545'; TP_4545
J1: HOLDER-BAT; SMD-CR1220-2
J2: AUDIO-8P'PJ-3536-L6S'; 8P-3.5-SMD
J3: HEADER-6P-65/35MIL; 6P-2.54-65/35MIL
J4: HEADER-2X4P-2.54; 2X4P-2.54
J7: CK_2X3_DD; CK_2X3
J13: HEADER_1X6; CK_1X6
JP: PAD-SOLDERJUMPERNC; 2P-SMD-3.3X2
L1, L3, L4: 120R 500mA; L0603
L2: 10uH; L0630
P1: JP
P2, P3: PAD-MARK; ROUND-MARK-1.0
POWER: BUTTON-4P-REINFORCE'TS-118E'; 4P-SMD-7X3.5X3.5H
PWR: green; D0603
Q1, Q3, Q4: 9013; SOT23
Q5: SI2305DS; SOT23
Q6, Q7: BSN20; SOT23
R1: 1k; R0603
R2, R15, R16: 47k; R0603
R3, R13, R14: 4.7k; R0603
R4: 100k; R0603
R5: 10k 1%; R0603
R6: 24k 1%; R0603
R8: 4.7k; 1206-8-3.3X2.4
R10: 0R; R0603
R11: DNP; R0603
R12: 68R; R0603
R17, R18, R19: 22R; R0603
R20, R21: 470R; R0603
R22: 100R; R0603
R23, R24: 1M; R0603
SIMHOLDER: SIMHOLDER3
T_4.1V, T_5V: PAD-TEST-POINT-CIRCLE'4545'; TP_4545; PARTNO DNP
T_EXT: PAD-TEST-POINT-CIRCLE'4545'; TP_4545; PARTNO DNP
U1: TD1410; SOP8
U2: SIM900
U3: ARDUINO'W/O-SILK'; ARDUINO-W/O-SILK

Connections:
3V3: U3.27 (3V3)
5V: C21.2, C22.2, Q5.2 (S), R8.7 (2), R8.8 (2), U3.26 (5V)
ADC: J13.3, U2.25 (ADC)
CTS: J4.4, U2.7 (CTS)
D9: JP.1, JP.2, R3.1, U3.10 (PB1/D9/PWM)
DCD: J4.2, U2.5 (DCD)
DISP_CLK: CLK.T, U2.11 (DISP_CLK)
DISP_CS: CS.T, U2.14 (DISP_CS)
DISP_D/C: D/C.T, U2.13 (DISP_D/C)
DISP_DATA: DATA.T, U2.12 (DISP_DATA)
DSR: J4.3, U2.6 (DSR)
EXT_VIN: C23.2, D1.+, U3.23 (VIN)
GND: ANT1.GND1, ANT1.GND2, ANT1.GND3, C2.-, C3.-, C4.1, C5.1, C6.1, C9.1, C10.1, C11.1, C12.2, C13.2, C15.1, C16.1, C17.2, C19.1, C20.2, C21.1, C23.1, C24.1, D4.1 (+), D5.1, D6.1, D7.1, D8.+, J1.- (V-), J2.2, J4.8, J13.4, P1.2, POWER.S1, POWER.S2, Q1.2 (E), Q3.2 (E), Q4.2 (E), R1.1, R2.2, R5.2, R15.2, R16.2, R23.2, R24.2, SIMHOLDER.6 (GND), U1.4 (GND), U2.17 (GND), U2.18 (GND), U2.20 (MIC_N), U2.29 (GND), U2.39 (GND), U2.45 (GND), U2.46 (GND), U2.53 (GND), U2.54 (GND), U2.58 (GND), U2.59 (GND), U2.61 (GND), U2.62 (GND), U2.63 (GND), U2.64 (GND), U2.65 (GND), U3.15 (GND), U3.24 (GND), U3.25 (GND)
GPIO1: J3.1, U2.40 (GPIO1/KBR4)
GPIO2: J3.2, U2.41 (GPIO2/KBR3)
GPIO3: J3.3, U2.42 (GPIO3/KBR2)
GPIO4: J3.4, U2.43 (GPIO4/KBR1)
GPIO5: J3.5, U2.44 (GPIO5/KBR0)
GPIO6: J3.6, U2.47 (GPIO6/KBC4)
GPIO7: U2.48 (GPIO7/KBC3)
GPIO8: U2.49 (GPIO8/KBC2)
GPIO9: U2.50 (GPIO9/KBC1)
GPIO10: U2.51 (GPIO10/KBC0)
GPIO11: U2.67 (GPIO11)
GPIO12: U2.68 (GPIO12)
HRXD: J7.2, Q6.3 (D), R8.1
HTXD: J7.5, Q7.3 (D), R8.2 (1)
LDBG_RX: U2.28 (DBG_RXD)
LDBG_TX: U2.27 (DBG_TXD)
LDTR: J4.6, U2.3 (DTR)
LINEIN_L: C8.2, U2.24 (LINEIN_L)
LINEIN_R: C7.2, U2.23 (LINEIN_R)
LRTS: J4.5, U2.8 (RTS)
LRXD: Q6.2 (S), R8.3 (1), U2.10 (RXD)
LTXD: Q7.2 (S), R8.4 (1), U2.9 (TXD)
MRXD: J7.1, U3.2 (PD1/D1/TX)
MTXD: J7.6, U3.1 (PD0/D0/RX)
unnamed: C10.2, R10.2, U2.60 (RF_ANT)
unnamed: D2.+, Q5.3 (D), R23.1, T_5V.T
unnamed: Q3.3 (C), R20.2
unnamed: R19.2, SIMHOLDER.4 (I/O)
unnamed: R18.1, SIMHOLDER.3 (CLK)
unnamed: R17.1, SIMHOLDER.2 (RST)
unnamed: D3/NET.-, R20.1
unnamed: Q3.1 (B), R13.2, R15.1
unnamed: PWR.-, R1.2
unnamed: R13.1, U2.52 (NETLIGHT)
unnamed: POWER.1, U2.2 (PWRKEY_OUT)
unnamed: R4.1, U1.7 (EN)
unnamed: C12.1, R12.1, U2.19 (MIC_P)
unnamed: C13.1, C14.2, C17.1, C18.2, L3.1, U2.21 (SPK_P)
unnamed: Q4.3 (C), R21.2
unnamed: D2/STA.-, R21.1
unnamed: Q4.1 (B), R14.2, R16.1
unnamed: C14.1, C15.2, C18.1, C19.2, L1.1, U2.22 (SPK_N)
unnamed: R14.1, U2.66 (STATUS)
unnamed: ANT1.D, C11.2, R10.1, R11.2
unnamed: C7.1, J13.6
unnamed: C8.1, J13.5
unnamed: C16.2, L4.1, R12.2
unnamed: Q5.1 (G), R22.1
unnamed: Q1.1 (B), R2.1, R3.2
unnamed: D8.-, L2.1, U1.3 (SW)
unnamed: C22.1, D4.2 (-), R22.2, R24.1
unnamed: D7.2, J2.1, L4.2
unnamed: C1.2, R5.1, R6.1, U1.5 (FB)
unnamed: D5.2, J2.4, L3.2
unnamed: D6.2, J2.3, L1.2
unnamed: P1.1, R11.1
PWM1: J13.1, U2.35 (PWM1)
PWM2: J13.2, U2.36 (PWM2)
PWRKEY: POWER.2, Q1.3 (C), U2.1 (PWRKEY)
RI: J4.1, U2.4 (RI)
SIM_CLK: R18.2, U2.32 (SIM_CLK)
SIM_DATA: R19.1, U2.31 (SIM_DATA)
SIM_RST: R17.2, U2.33 (SIM_RST)
SIM_VDD: C20.1, SIMHOLDER.1 (VCC), U2.30 (SIM_VDD)
SRXD: J7.3, U3.9 (PB0/D8)
STXD: J7.4, U3.8 (PD7/D7)
VBAT: C1.1, C3.+, C4.2, C5.2, C9.2, D2/STA.+, D3/NET.+, L2.2, PWR.+, R6.2, T_4.1V.T, U2.55 (VBAT), U2.56 (VBAT), U2.57 (VBAT)
VDD_EXT: J4.7, Q6.1 (G), Q7.1 (G), R8.5 (2), R8.6 (2), U2.15 (VDD_EXT)
VIN: C2.+, C24.2, D1.-, D2.-, R4.2, T_EXT.T, U1.2 (VIN)
VRTC: C6.2, J1.+ (V+), U2.26 (VRTC)

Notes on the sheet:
close to connector
debug
soft start
voltage detect threshold 7V
connector
6mil

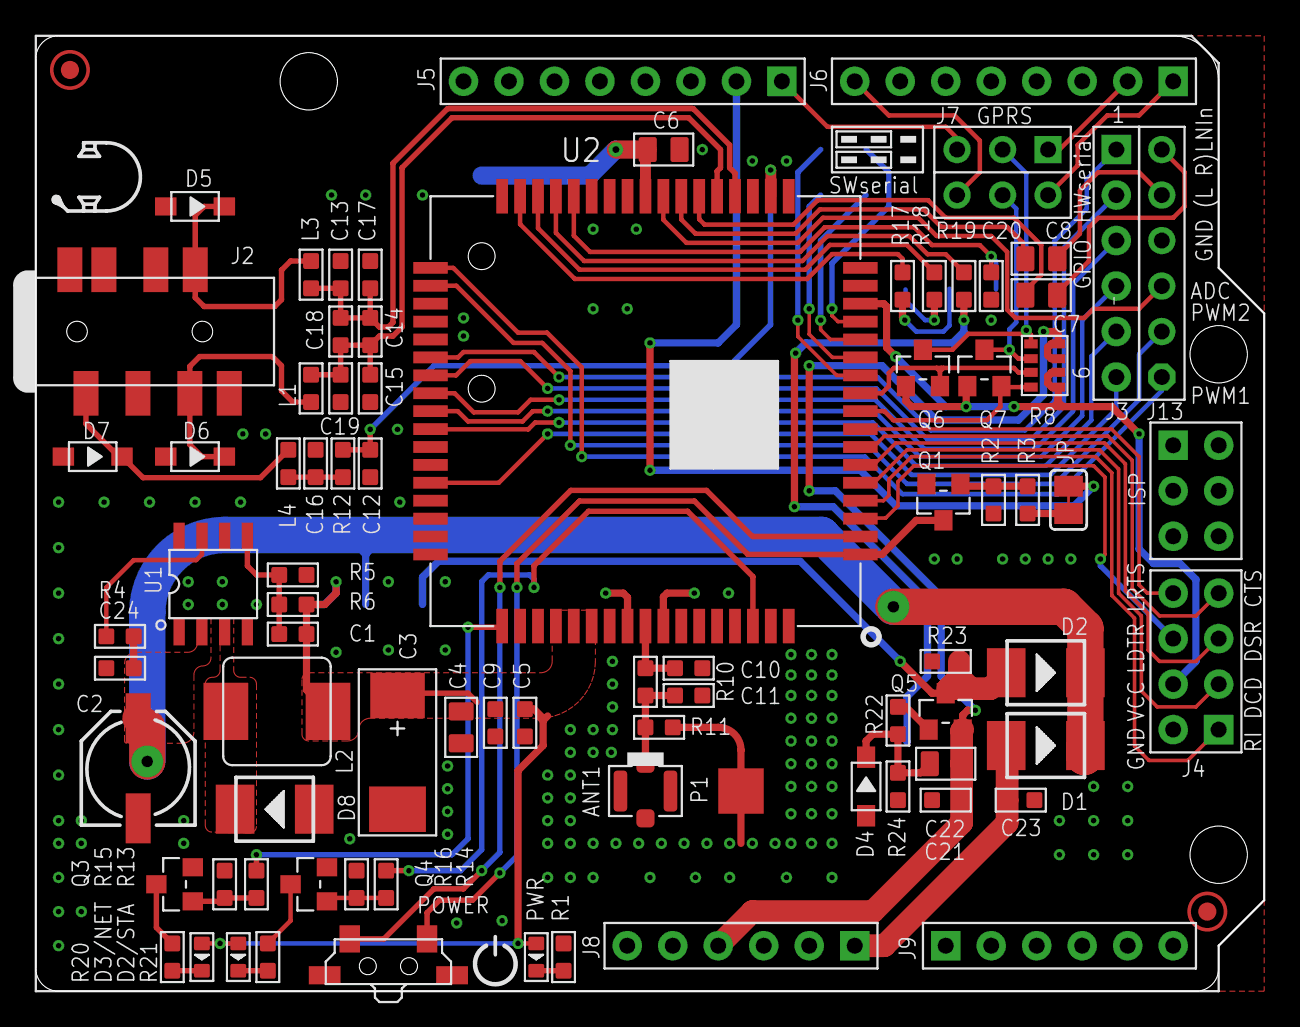
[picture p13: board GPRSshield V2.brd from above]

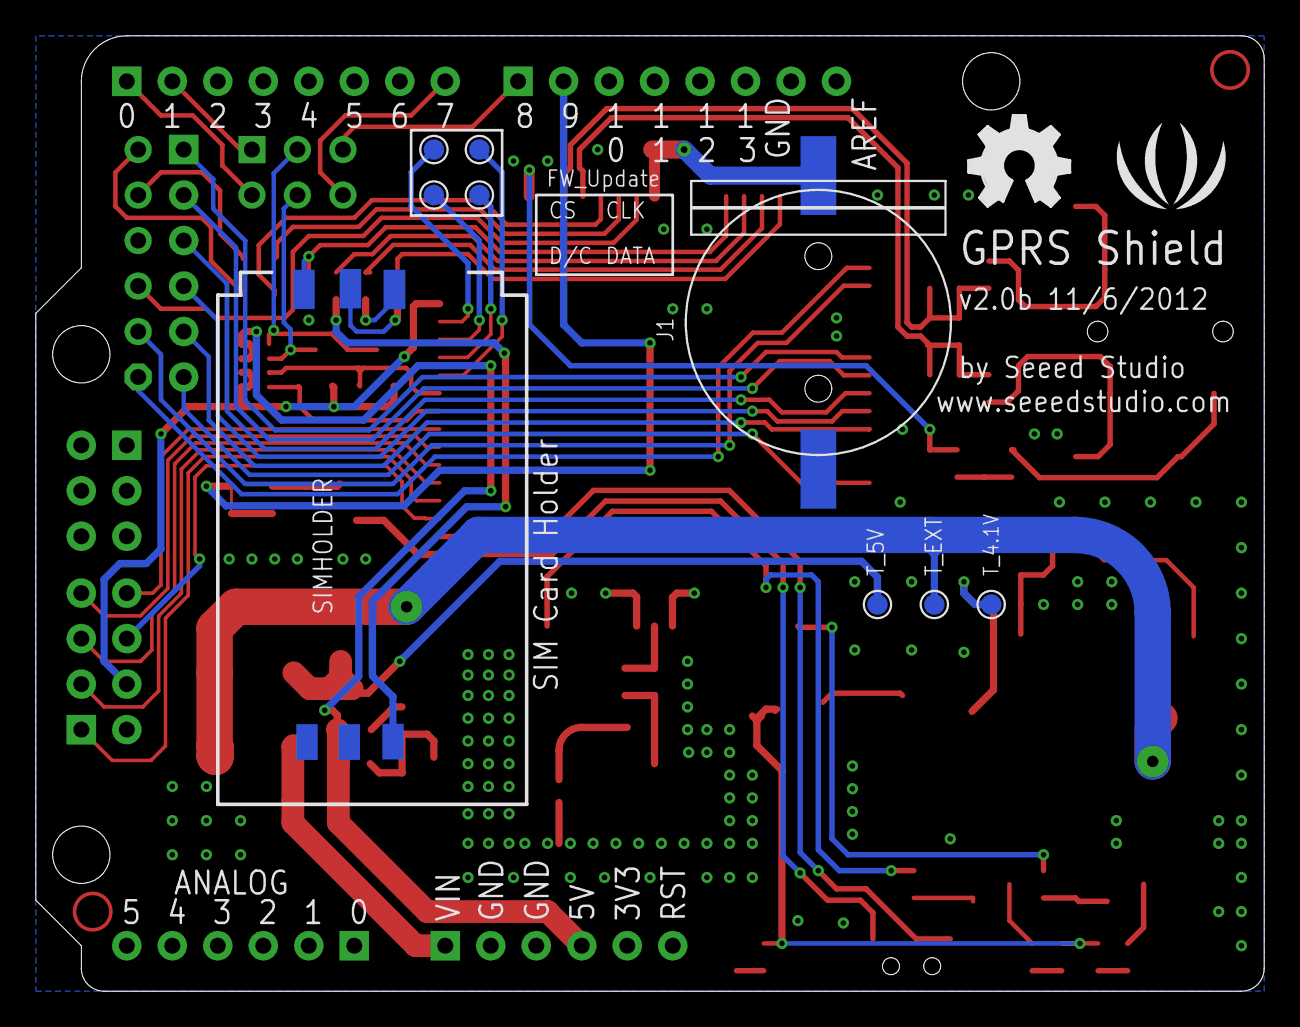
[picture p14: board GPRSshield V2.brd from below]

Board: 2 copper layers, 68.6 x 53.3 mm, 91 parts (11 on the bottom side), 74 nets.

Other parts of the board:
U$26: LOGO_SILK
U$28: OSHW_FILLX200_NOTEXT

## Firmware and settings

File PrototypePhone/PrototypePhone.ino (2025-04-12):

/******************************************************************************************************

                                   Licensed under the GPLv3

    This code running on an Arduino combined with the GPRS shield from Seeedstudio, and the
  4.3" tft touch screen from Adafrit, using the RA8875 driver from Adafruit, it will produce
  a functioning phone

  CURRENT FEATURES:
  =================
  Place calls, receive calls, hang up calls, ignore calls
  Dialing numbers and displayed on-screen
  In call DTMF Tones
  Read incoming data from SIM Module, and provide functions and executions based on data
  Display prompt for incoming texts
  Display time in a human readable format including AM/PM and updated at 00 seconds
  Seperate and Defined Screens with functions and touch values per screen (ie. Phone vs SMS)
  Read individual texts defined/sorted by index
  Delete SMS
  Caller ID
  Display Missed Calls
  Passcode along with 5 second lapse before start
  Notification LEDs
  Display has timeout sleep based on Touch Inactivity
  Automatic Power On for SIM Module
  Screen Darkening clockTime before Sleep mode

*******************************************************************************************************/






//==================================================================================================================================================

//   DECLARATIONS AND INITIALIZATIONS

//==================================================================================================================================================


#include <SPI.h>
#include "Adafruit_GFX.h"
#include "Adafruit_RA8875.h"

// Define pins used for RA8875 driver
#define RA8875_INT 5
#define RA8875_RESET 6
#define RA8875_CS 9

// mew object tft to use RA8875
Adafruit_RA8875 tft = Adafruit_RA8875(RA8875_CS, RA8875_RESET);

// TFT Screen Magic Numbers
// Numpad
int topRow_xMin = 689;
int topRow_xMax = 778;
int secondRow_xMin = 529;
int secondRow_xMax = 627;
int thirdRow_xMin = 347;
int thirdRow_xMax = 442;
int bottomRow_xMin = 194;
int bottomRow_xMax = 285;

int leftColumn_yMin = 190;
int leftColumn_yMax = 305;
int middleColumn_yMin = 443;
int middleColumn_yMax = 577;
int rightColumn_yMin = 690;
int rightColumn_yMax = 872;

// test values
const int text_size = 2;
const int delay_input = 2;

// Initialize touch screen callCharBuf_Index values
uint16_t touchValue_X = 0, touchValue_Y = 0;

// Touch Event
bool touched = false;

// Keep track of clockTime since Last Touched event
unsigned long lastInteract = 0;

// Call Buffer
char callCharBuf[20] = {'A', 'T', 'D'};
int callCharBuf_Index = 3;

// Text Messaging array, store from bufGPRS, start and finish of text message read from GPRS
char sendCharText[11] = {'A', 'T', '+', 'C', 'M', 'G', 'R', '=', '0', '1', '\r'};
char textBuf[256] = "";
int textBuf_Index = 0;
bool viewMessage = false;
bool textReadStarted = false;
bool textReady = false;
bool newMessage;

// resultStr defines the functions of the phone
char resultStr[256] = "";
int resultStr_Index = 0;
bool resultStrChange = false;

// Store incoming data from GPRS shield
chat bufGPRS[256] = "";
int bufGPRS_Index = 0;

// Keep track of whether in call or not
bool inCall = false;

// Keep track of missed Calls and new Messages
int countRings = 0;
char missedCalls = 0;
char old_missedCalls = 0;
char newMessages = 0;
char old_newMessages = 0;

// Battery Condition updated with clockTime mintues
bool displayBattery = false;
bool charging = false;
char battLevel[2];
char battVoltage[4];

// Keep track of clockTime elapsed since last query for clockTime (defined per 60 seconds)
unsigned long currentTime = 0;
unsigned long displayTime = 60;
bool displayClockTime = false;
char clockTime[20];

// Define where on the phone the User is and what part of the phone functions to jump to
bool atHomeScreen = false;
bool atPhoneScreen = false;
bool atTextMessageScreen = false;
bool atAnswerScreen = false;
bool atAnsweredScreen = false;
bool atPasscodeScreen = true;
bool atSendTextScreen = false;

// Display State and clockTimes
bool displaySleep = false;
unsigned int displayClockTimeout = 60 * 1000;
unsigned int sleepDarken = 10 * 1000;

// realPasscode is your passcode, displays 8 characters correctly but technically can be as long as desired
const int max_password_length = 16;
char realPasscode[max_password_length] = "1234";
char realPasscode_Index = 0;
char passcode[max_password_length] = "";
int passcode_Index = 0;
unsigned long startPasscodeLock = 0;
unsigned int passcodeClockTimeout = 10 * 1000;
const int x_Position = 60;

// Notification LEDs
const int missedCallsLED = 10;
const int messageLED = 11;

// Power Button
const int powerButton = 13;

// Delay for write on Serial1 baud, bitDepth is CPU/MCU/MPU bits
const double bitDepth = 8;
const double buadRateGPRS = 19200;
unsigned int delayForUart = (buadRateGPRS / (bitDepth + 2.0));

// Keep track of in call clockTime
unsigned int prevCallTime = 0;
unsigned int callTime = 0;


//==================================================================================================================================================

//   END OF DECLARATIONS AND INITIALIZATIONS

//==================================================================================================================================================









void setup() {
  //==================================================================================================================================================

  //   MAIN SETUP

  //==================================================================================================================================================

  //=========================
  //  Start Serial Monitors
  //=========================

  // Start serial from Arduino to USB
  Serial.begin(19200);

  // Start serial from GPRS to Arduino
  Serial1.begin(buadRateGPRS);

  //=========================
  //    Power on Display
  //=========================

  // Initialize the RA8875 driver
  Serial.println("RA8875 start");
  while (!tft.begin(RA8875_480x272)) {
    Serial.println("RA8875 Not Found!");
  }
  Serial.println("Found RA8875");

  // Turn display backlight and PWM output from driver
  tft.displayOn(true);
  tft.GPIOX(true);
  tft.PWM1config(true, RA8875_PWM_CLK_DIV1024);
  tft.PWM1out(255);

  // Set pin for touch resistance of tft display
  pinMode(RA8875_INT, INPUT_PULLUP);
  digitalWrite(RA8875_INT, HIGH);
  tft.touchEnable(true);
  delay(20);

  // Flip the horizontal scanning and text
  tft.scanH_flip(true);
  tft.textRotate(true);

  //=========================
  //  Starting Screen
  //=========================

  // Set Screen
  drawPasscodeScreen();

  //=========================
  //   Module Power Check
  //=========================

  // Power on the Sim Module
  pinMode(26, INPUT);
  pinMode(3, OUTPUT);
  bool powerState = digitalRead(26);

  // if module is powered down
  if (!powerState) {
    do {
      // turn module on
      digitalWrite(3, HIGH);
      delay(3000);
      powerState = digitalRead(26);
      delay(200);
    } while (!powerState);
    digitalWrite(3, LOW);

    // wait for module to start sending data
    while (!Serial1.available()) {
    }

    // let module finish data, then print report to serial monitor
    char initChip[1024];
    Serial1.readBytes(initChip, 1024);
    for (int i = 0; i < 1024; i++) {
      Serial.write(initChip[i]);
    }
  }

  //=========================
  //  Module Function Check
  //=========================

  // Update clockTime from network
  Serial1.write("AT+CLTS=1\r");
  delay((10 / delayForUart) * 1000);

  // Make sure Caller ID is on
  Serial1.write("AT+CLIP=1\r");
  delay((10 / delayForUart) * 1000);

  // Make sure Text Mode is readable (not PDU)
  Serial1.write("AT+CMGF=1\r");
  delay((10 / delayForUart) * 1000);

  // Enable Sleep Mode on SIM900 (wake-up on serial)
  //Serial1.write("AT+CSCLK=2\r");
  //delay((11 / delayForUart) * 1000);

  // Check clockTime
  Serial1.write("AT+CCLK?\r");
  delay((9 / delayForUart) * 1000);

  currentTime = millis();
  lastInteract = currentTime;
  startPasscodeLock = currentTime;

  pinMode(powerButton, INPUT_PULLUP);
  digitalWrite(powerButton, HIGH);
}
//==================================================================================================================================================

//   END OF SETUP

//==================================================================================================================================================









void loop() {
  //==================================================================================================================================================

  //   MAIN PROGRAM

  //==================================================================================================================================================

  //=========================
  //          Time
  //=========================
  currentTime = (millis() / 1000);


  //=========================
  //      SERIAL READS
  //=========================
  // When data is coming from GPRS store into bufGPRS
  if (Serial1.available()) {
    bufGPRS[bufGPRS_Index++] = (char)Serial1.read();
  }
  bufGPRS[bufGPRS_Index] = '\0'
  Serial1.flush();

  //When data is coming from USB write to GPRS shield
  if (Serial.available()) {
    Serial1.write(Serial.read());
  }
  Serial.flush();


  //=========================
  //     GPRS FUNCTIONS
  //=========================
  if (strlen(bufGPRS) >= 2 && strcmp(&bufGPRS[strlen(bufGPRS) - 2], "\r\n") == 0) {
    resultStrChange = true;
  
    if (strcmp(bufGPRS, "\r\n") == 0) {
      bufGPRS[0] = '\0'; // Clear buffer
    }
    else if (strncmp(bufGPRS, "+CCLK", 5) == 0) {
      displayClockTime = true;
    }
    else if (strncmp(bufGPRS, "+CBC", 4) == 0) {
      displayBattery = true;
    }
    else if (strncmp(bufGPRS, "+CLIP", 5) == 0) {
      strcpy(resultStr, "Caller ID");
    }
    else if (strcmp(bufGPRS, "RING\r\n") == 0) {
      strcpy(resultStr, "Ringing");
      atAnswerScreen = true;
      atHomeScreen = false;
      atPhoneScreen = false;
      atTextMessageScreen = false;
    }
    else if (strncmp(bufGPRS, "+CMTI", 5) == 0) {
      newMessage = true;
    }
    else if (strncmp(bufGPRS, "+CMGR", 5) == 0) {
      strcpy(resultStr, "Text Read");
    }
    else if (strcmp(bufGPRS, "OK\r\n") == 0) {
      strcpy(resultStr, "OK");
    }
    else if (strcmp(bufGPRS, "NO CARRIER\r\n") == 0) {
      strcpy(resultStr, "No Carrier");
    }
    else if (strcmp(bufGPRS, "Call Ready\r\n") == 0) {
      Serial1.write("AT+CCLK?\r");
      delay((11 / delayForUart) * 1000);
      strcpy(resultStr, "Call Ready");
    }
    else if (strcmp(bufGPRS, "NORMAL POWER DOWN\r\n") == 0) {
      strcpy(resultStr, "NORMAL POWER DOWN");
    }
  }  


  //===========================================================================================================================

  //  Defined functions per screen

  //===========================================================================================================================


  //================================================================================================
  //   HOME SCREEN
  //================================================================================================
  if (atHomeScreen) {

    //==========================================================
    //   MISSED CALLS PROMPT
    //==========================================================
    if (missedCalls > 0) {
      tft.textMode();
      tft.textRotate(true);
      tft.textColor(RA8875_WHITE, RA8875_BLACK);
      tft.textEnlarge(1);
      delay(delay_input);
      tft.textSetCursor(270, 15);
      tft.textWrite("Missed Calls ");
      char missedBuf[4]; // enough for "999\0"
      itoa(missedCalls, missedBuf, 10); // base 10
      tft.writeData(missedBuf);
    }

    //==========================================================
    //   NEW MESSAGE PROMPT
    //==========================================================
    if (newMessages > old_newMessages) {
      old_newMessages = newMessages;
      // clear number display and number pad
      tft.graphicsMode();
      tft.fillRect(160, 0, 100, 279, RA8875_BLACK);

      // Prompt User new message received
      tft.textMode();
      tft.textRotate(true);
      tft.textColor(RA8875_WHITE, RA8875_BLACK);
      tft.textEnlarge(1);
      delay(delay_input);
      tft.textSetCursor(160, 20);
      tft.textWrite("New Message ");
      tft.writeCommand(RA8875_MRWC);
      tft.writeData(newMessages);
      delay(1);

      //==========================================================
      //   VIEW MESSAGE PROMPT
      //==========================================================
      tft.textMode();
      tft.textRotate(true);
      tft.textColor(RA8875_WHITE, RA8875_BLACK);
      tft.textEnlarge(1);
      delay(delay_input);
      tft.textSetCursor(210, 40);
      tft.textWrite("View Message");
      viewMessage = true;
    }
  }

  //================================================================================================
  //   TEXT MESSAGE SCREEN
  //================================================================================================
  else if (atTextMessageScreen) {
    if (textReady) {
      // No need to copy into textCharRead — textBuf IS the char buffer
  
      tft.textMode();
      tft.textColor(RA8875_WHITE, RA8875_BLACK);
      tft.textEnlarge(1);
      delay(delay_input);
  
      // Display Index Number
      tft.textSetCursor(45, 100);
      tft.writeCommand(RA8875_MRWC);
      for (int i = 8; i <= 9; i++) {
        tft.writeData(sendCharText[i]);
        delay(1);
      }
  
      // Find start/end of caller number
      int receivingNumStart = strchr(textBuf, ',') - textBuf;
      if (textBuf[receivingNumStart + 2] == '+') {
        receivingNumStart += 3;
      } else {
        receivingNumStart += 2;
      }
  
      int receivingNumEnd = strchr(&textBuf[receivingNumStart], ',') - textBuf - 1;
  
      // Display caller number
      tft.textEnlarge(0);
      delay(delay_input);
      tft.textSetCursor(130, 60);
      tft.writeCommand(RA8875_MRWC);
      for (int i = receivingNumStart; i < receivingNumEnd; i++) {
        tft.writeData(textBuf[i]);
        delay(1);
      }
  
      // Find start and end of message
      char *firstCR = strchr(textBuf, '\r');
      char *secondCR = strchr(firstCR + 1, '\r');
  
      int messageStart = firstCR - textBuf + 2;
      int messageEnd = secondCR - textBuf;
  
      // Display message body
      tft.textSetCursor(175, 0);
      tft.textEnlarge(0);
      delay(delay_input);
      tft.writeCommand(RA8875_MRWC);
      for (int i = messageStart; i < messageEnd; i++) {
        tft.writeData(textBuf[i]);
        delay(1);
      }
  
      textReady = false;
      textBuf[0] = '\0'; // Clear buffer
  
      clearNotifications();
    }
  }  

  //================================================================================================
  //   ANSWER SCREEN
  //================================================================================================
  else if (atAnswerScreen && resultStrChange) {

    //==========================================================
    //  DISPLAY INCOMING CALL
    //==========================================================
    if (resultStr == "Ringing") {
      resultStrChange = false;
      //=====================
      //  WAKE UP SCREEN
      //=====================
      if (countRings == 0) {
        tft.displayOn(true);
        tft.PWM1out(255);
        tft.touchEnable(true);
        displaySleep = false;
        drawAnswerScreen();
      }
      countRings++;
      lastInteract = millis();
      tft.textMode();
      tft.textColor(RA8875_WHITE, RA8875_BLACK);
      tft.textEnlarge(1);
      delay(delay_input);
      tft.textSetCursor(75, 20);
      tft.textWrite("Incoming Call");
    }

    //==========================================================
    //    DISPLAY CALLER ID
    //==========================================================
    else if (resultStr == "Caller ID") {
      resultStrChange = false;

      // Find the first and second double quotes
      char *startPtr = strchr(bufGPRS, '"');
      char *endPtr = startPtr ? strchr(startPtr + 1, '"') : NULL;
    
      if (startPtr && endPtr && endPtr > startPtr) {
        // Display caller ID between quotes
        tft.textMode();
        tft.textColor(RA8875_WHITE, RA8875_BLACK);
        tft.textEnlarge(1);
        delay(delay_input);
        tft.textSetCursor(125, 20);
        tft.writeCommand(RA8875_MRWC);
    
        // Print each character between the quotes
        for (char *p = startPtr + 1; p < endPtr; p++) {
          tft.writeData(*p);
          delay(1);
        }
      }
    }
  }

  //==========================================================
  //   CALL LOST (Service drop or call terminated)
  //==========================================================
  if (resultStr == "No Carrier" && resultStrChange) {
    resultStrChange = false;
    inCall = false;
    clearScreen();
    tft.textMode();
    tft.textColor(RA8875_WHITE, RA8875_BLACK);
    tft.textEnlarge(text_size);
    delay(delay_input);
    tft.textSetCursor(100, 15);
    tft.textWrite("Call Ended");
    delay(2000);
    if (atPasscodeScreen) {
      drawPasscodeScreen();
    } else {
      drawHomeScreen();
    }
  }

  //==========================================================
  //      CALL READY
  //==========================================================
  if (resultStr == "Call Ready" && resultStrChange) {
    resultStrChange = false;
    lastInteract = millis();
    startPasscodeLock = millis();
    drawPasscodeScreen();
    Serial1.write("AT+CCLK?\r");
    delay((9 / delayForUart) * 1000);
  }

  /*
      //==========================================================
      //       SIM900 OFF
      //==========================================================
      if (resultStr == "NORMAL POWER DOWN" && resultStrChange) {

        // Display to User GPRS shield is off
        tft.textMode();
        tft.textColor(RA8875_WHITE, RA8875_BLACK);
        tft.textEnlarge(text_size);
        delay(delay_input);
        tft.textSetCursor(250, 50);
        tft.textWrite("SIM900m");
        tft.textSetCursor(300, 50);
        tft.textWrite("POWERED");
        tft.textSetCursor(350, 50);
        tft.textWrite("  OFF");
      }
    }
  */
  //===========================================================================================================================

  //  END OF SCREEN FUNCTIONS

  //===========================================================================================================================





  //===========================================================================================================================

  //  BACKGROUND TASKS

  //===========================================================================================================================

  //==========================================================
  //   Battery Display
  //==========================================================
  if (displayBattery) {
    displayBattery = false;

    char *firstComma = strchr(bufGPRS, ',');
    if (firstComma && strlen(firstComma) >= 8) {
      charging = *(firstComma - 1) - '0';  // char to int

      battLevel[0] = *(firstComma + 1);
      battLevel[1] = *(firstComma + 2);

      battVoltage[0] = *(firstComma + 4);
      battVoltage[1] = *(firstComma + 5);
      battVoltage[2] = *(firstComma + 6);
      battVoltage[3] = *(firstComma + 7);
    }

    batteryDisplay();
  }

  //==========================================================
  //      clockTime DISPLAY
  //==========================================================
  if (displayClockTime) {
    printClockTime();
    displayClockTime = false; // Ensure flag is reset

    // Find the last quote (") to locate seconds
    char *lastQuote = strrchr(bufGPRS, '"');
    if (lastQuote && (lastQuote - bufGPRS) >= 5) {
      int secondTens = (lastQuote[-5] - '0') * 10;
      int secondOnes = (lastQuote[-4] - '0');
      displayTime -= (secondTens + secondOnes);
    }

    // Update Battery Indicator
    Serial1.write("AT+CBC\r");
    Serial1.flush();
  }
  else if (currentTime >= displayTime) {
    displayTime += 60;
    Serial1.write("AT+CCLK?\r");
    Serial1.flush();
  }


  //==========================================================
  //   MISSED/NEW MESSAGES COUNT
  //==========================================================
  if (newMessage) {
    newMessages++;
    //=========================
    //    NEW MESSAGE INDEX
    //=========================
    char *comma = strchr(bufGPRS, ',');
    if (comma) {
      if (*(comma + 2) == '\r') {
        sendCharText[9] = *(comma + 1);
      } else {
        sendCharText[8] = *(comma + 1);
        sendCharText[9] = *(comma + 2);
      }
    }

    newMessage = false;
  }

  //==========================================================
  //   MISSED CALLS COUNT
  //==========================================================
  if (countRings > 0 && resultStr == "No Carrier" && resultStrChange) {
    missedCalls++;
    countRings = 0;
  }

  //==========================================================
  //    NOTIFICATION LEDS
  //==========================================================
  if (missedCalls >= 1 && missedCalls != old_missedCalls) {
    old_missedCalls = missedCalls;
    analogWrite(missedCallsLED, 255);
    tft.textMode();
    tft.textColor(RA8875_RED, RA8875_BLACK);
    tft.textEnlarge(1);
    delay(delay_input);
    tft.textSetCursor(0, 0);
    tft.textWrite("!");
  }
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

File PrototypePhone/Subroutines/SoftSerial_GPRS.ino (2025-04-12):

//Serial Relay - Arduino will patch a 
//serial link between the computer and the GPRS Shield
//at 19200 bps 8-N-1
//Computer is connected to Hardware UART
//GPRS Shield is connected to the Software UART 
 
#include <SoftwareSerial.h>
 
SoftwareSerial GPRS(7, 8);
unsigned char buffer[64]; // buffer array for data recieve over serial port
int count=0;     // counter for buffer array 
void setup()
{
  GPRS.begin(9600);               // the GPRS baud rate   
  Serial.begin(19200);             // the Serial port of Arduino baud rate.
 
}
 
void loop()
{
  if (GPRS.available())              // if date is comming from softwareserial port ==> data is comming from gprs shield
  {
    while(GPRS.available())          // reading data into char array 
    {
      buffer[count++]=GPRS.read();     // writing data into array
      if(count == 64)break;
  }
    Serial.write(buffer,count);            // if no data transmission ends, write buffer to hardware serial port
    clearBufferArray();              // call clearBufferArray function to clear the storaged data from the array
    count = 0;                       // set counter of while loop to zero
 
 
  }
  if (Serial.available())            // if data is available on hardwareserial port ==> data is comming from PC or notebook
    GPRS.write(Serial.read());       // write it to the GPRS shield
}
void clearBufferArray()              // function to clear buffer array
{
  for (int i=0; i<count;i++)
    { buffer[i]=NULL;}                  // clear all index of array with command NULL
}

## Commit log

2014-08-18 PrototypePhone
    08/18/2014, not quite finished
2014-08-20 8/19
    using Due, RA8875, 4.3" TFT, new libs
    [GPRSshield V2.brd, GPRSshield V2.sch]
2014-08-25 number pad sensing and Due references
    [Arduino_DUE_V02b.brd, Arduino_DUE_V02b.sch]
2014-11-05 Answer Screen Bug fix
    [PrototypePhone.ino]
2014-11-05 caller ID, bug fixes
    [PrototypePhone.ino]
2014-11-05 caller id bug fix
    [PrototypePhone.ino]
2014-11-20 additional bug fixes RA8875.cpp
    [PrototypePhone.ino]
2014-12-07 orrection delayForUart logical error
    [PrototypePhone.ino]
2014-12-07 Button Lock bug fix
    [PrototypePhone.ino]
2014-12-07 AM time bug fix
    [PrototypePhone.ino]
2016-01-08 Multiple Bug Fixes, Code speed-ups, feature adds
    Simplified code tx and ty values, as well as position values
    Simplified the time placement values
    Added time display to passcode screen and reformated the display of time
    1/5/2016
    Added transitor based power control of SIM module
    Removed psuedo-boot sequence
    1/6/2016
    Added Ignore Call feature
    12 am is now displayed correctly instead of 00 am
    Date display comma position corrected
    1/7/2016
    Clock is now set to refresh at power up regardless of current power of
    SIM module
    Added Answered Screen to include call duration
    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
    [Arduino_DUE_V02b.brd, Arduino_DUE_V02b.sch]
2016-01-18 Bug fix 1-18-2016
    Removed or commented out unused variables, corrected code, created new
    folder for easy "install" and usage of code on arduino
    [PrototypePhone.ino, ts_calibration.ino]
2016-07-14 Major Bug Fixes and Improvements
    Libraries Updated
    Call Ended Fixed
    Fixed Debouncing Issue and improved touch algorithum
    Added Display for Battery Level
    Removed repeative code
    Text Screen and text message functions bug fixes
    Clear Notifications when selected (still needs intelligence of when
    read)
    SMS Send Screen fully displayed and formatted correctly, along with time
    [PrototypePhone.ino]
2016-07-14 Wrong INO File Upload
    [PrototypePhone.ino]
2016-11-02 Bug Fixes && Code Improvements
    [PrototypePhone.ino]
2025-04-12 - major cleanup
    [Arduino_DUE_V02b.brd, Arduino_DUE_V02b.sch, GPRSshield V2.brd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]
